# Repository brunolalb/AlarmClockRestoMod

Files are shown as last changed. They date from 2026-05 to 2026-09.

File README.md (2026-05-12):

# AlarmClockRestoMod
ESP32 Software for an Alarm Clock Resto Mod.

The idea is to use the components of an old alarm clock and replace the electronics with an ESP32, adding a lot of features to it. From an outside perspective, the clock will look as original as possible.

## Features

* WiFi connectivity
  * NTP time synchronization
  * Web server for advanced configuration
  * OTA updates
* Bluetooth connection from phone and to headphone/speaker
* Clock:
  * 7 segment display with dimming function
  * RTC for time keeping when power is out
* Alarms:
  * Configurable via web interface (advanced) or via buttons (only next alarm)
  * Configurable music or internet radio or buzzer for each alarm
  * Snooze function (delay configurable via web interface)
  * Vacation mode (turn off all alarms for a configurable period of time)
* Radio:
  * Internet radio stations configurable via web interface
  * Tuner button to switch between internet radio stations or playlists on microSD card
* microSD Card to store pre-owned Music, playlists and configuration files

## Components Overview
* Display is a 7 segment 4 digits with a TM1637, dimmable by software
* DS3231 for time keeping when power is out
* microSD Card with:
  * MP3 songs and playlists
  * Configuration file for radio stations (accepts internet radio station or playlist)
  * Configuration file for different alarms
* The tuner button of the alarm clock is a variable capacitor (10 - 500pF) read via a MPR121
  * Each frequency corresponds to an internet radio
* Bluetooth to connect to cellphone (play music from it) or to an external speaker/headphone
* Normal speaker connected via MAX98357A
* Buttons (Telefunken Digital Electronic 101):
  * 2 momentary switches to set time (Fast and slow)
  * 1 latching switch to turn on auto dimm/full light on display
  * 3 mutually-exclusive latching switches: show time, show next alarm (use the 2 momentary switches to set the alarm time) or "sleep mode" (turn on radio for 60min)
  * 1 momentary switch for sleep function (during alarm, press once to delay alarm in 5min, press twice to turn off alarm; during sleep mode, turn off radio)
  * 1 Volume slider (potentiometer)
  * 4 mutually-exclusive latching switches: turn on radio, turn off radio, alarm with radio, alarm with buzzing sound
  * 2 mutually-exclusive latching switches: radio corresponds to playlists, radio corresponds to internet radios
  * 1 momentary switch: one click (tries to connect to configured bluetooth speaker), two clicks (turns on bluetooth for phone to connect); if bluetooth connection is not successful after 1 min, turn off bluetooth
* Alarms:
  * fully configurable via web interface
  * choose days of the week
  * snooze time configurable
  * vacation mode
  * music and internet radio configured via web interface

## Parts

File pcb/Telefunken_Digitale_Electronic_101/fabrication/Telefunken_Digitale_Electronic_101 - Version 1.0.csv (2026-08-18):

DNP | Reference | Qty | Name | Value | Description | Footprint
 | C1,C3,C7 | 3 |  | 100n | Unpolarized capacitor | Capacitor_SMD:C_0603_1608Metric_Pad1.08x0.95mm_HandSolder
 | C2 | 1 |  | 10u | Polarized capacitor | Capacitor_THT:CP_Radial_D4.0mm_P2.00mm
 | C4,C8 | 2 |  | 10u | Unpolarized capacitor | Capacitor_SMD:C_0805_2012Metric_Pad1.18x1.45mm_HandSolder
 | C5,C6 | 2 |  | 100p | Unpolarized capacitor | Capacitor_SMD:C_0603_1608Metric_Pad1.08x0.95mm_HandSolder
 | DISPLAY1 | 1 | DISPLAY |  | 4 Digit 7-Segment Display with dots 0.8" | RadioWecker:8041BS-1
 | J1 | 1 | POWER | Conn_01x02_MountingPin | Generic connectable mounting pin connector, single row, 01x02, script generated (kicad-library-utils/schlib/autogen/connector/) | RadioWecker:JST_S2B-XH-SM4-TB
 | J2 | 1 | Display | Conn_01x02_MountingPin | Generic connectable mounting pin connector, single row, 01x02, script generated (kicad-library-utils/schlib/autogen/connector/) | Connector_Molex:Molex_PicoBlade_53261-0271_1x02-1MP_P1.25mm_Horizontal
 | J3 | 1 | RTC | Conn_01x04_MountingPin | Generic connectable mounting pin connector, single row, 01x04, script generated (kicad-library-utils/schlib/autogen/connector/) | Connector_Molex:Molex_PicoBlade_53261-0471_1x04-1MP_P1.25mm_Horizontal
 | J4 | 1 | BT_TIME | Conn_01x02_Socket | Generic connector, single row, 01x02, script generated | Connector_PinSocket_2.54mm:PinSocket_1x02_P2.54mm_Vertical
 | J5 | 1 | BT_SIGNAL | Conn_01x02_Socket | Generic connector, single row, 01x02, script generated | Connector_PinSocket_2.54mm:PinSocket_1x02_P2.54mm_Vertical
 | J6 | 1 | BT_SLEEP_FRONT | Conn_01x02_Socket | Generic connector, single row, 01x02, script generated | Connector_PinSocket_2.54mm:PinSocket_1x02_P2.54mm_Vertical
 | J7 | 1 | BT_ILLUM | Conn_01x02_Socket | Generic connector, single row, 01x02, script generated | Connector_PinSocket_2.54mm:PinSocket_1x02_P2.54mm_Vertical
 | J8 | 1 | BT_SLEEP_TOP | Conn_01x02_Socket | Generic connector, single row, 01x02, script generated | Connector_PinSocket_2.54mm:PinSocket_1x02_P2.54mm_Vertical
 | R3,R4 | 2 |  | 10K | Resistor | Resistor_SMD:R_0603_1608Metric_Pad0.98x0.95mm_HandSolder
 | SW1 | 1 | FAST | SW_Push | Push button switch, generic, two pins | RadioWecker:TACT_SWITCH_3.2X4.2X2.5MM
 | SW2 | 1 | SLOW | SW_Push | Push button switch, generic, two pins | RadioWecker:TACT_SWITCH_3.2X4.2X2.5MM
 | U1 | 1 |  | DS3231 | DS3231 AT24C32 IIC module precision Real time clock quare memory for Arduino | RadioWecker:DS3231
 | U2 | 1 |  | TM1637_SOP20 | LED Drive Control Special Circuit | RadioWecker:SOIC127P1035X255-20N
DNP | R1,R2 | 2 |  | 2k2 | Resistor | Resistor_SMD:R_0603_1608Metric_Pad0.98x0.95mm_HandSolder

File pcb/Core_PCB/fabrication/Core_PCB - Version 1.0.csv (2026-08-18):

DNP | Reference | Name | Qty | Value | Description | Footprint
 | A1 |  | 1 | Arduino_Nano_ESP32_Socket | Socket for Arduino Nano ESP32 | RadioWecker:Arduino_Nano_ESP32_Socket
 | C1 |  | 1 | 10u | Polarized capacitor | Capacitor_THT:CP_Radial_D4.0mm_P2.00mm
 | C2,C3,C5,C8,C9,C10,C11,C12,C14,C15,C16,C17 |  | 12 | 100n | Unpolarized capacitor | Capacitor_SMD:C_0603_1608Metric_Pad1.08x0.95mm_HandSolder
 | C4,C6,C7 |  | 3 | 10u | Unpolarized capacitor | Capacitor_SMD:C_0805_2012Metric_Pad1.18x1.45mm_HandSolder
 | C13 |  | 1 | 1u | Unpolarized capacitor | Capacitor_SMD:C_0805_2012Metric_Pad1.18x1.45mm_HandSolder
 | J1 | POWER | 1 | Conn_01x02_MountingPin | Generic connectable mounting pin connector, single row, 01x02, script generated (kicad-library-utils/schlib/autogen/connector/) | RadioWecker:JST_S2B-XH-SM4-TB
 | J2 | DISPLAY_POWER | 1 | Conn_01x02_MountingPin | Generic connectable mounting pin connector, single row, 01x02, script generated (kicad-library-utils/schlib/autogen/connector/) | RadioWecker:JST_S2B-XH-SM4-TB
 | J3 | DISPLAY | 1 | Conn_01x02_MountingPin | Generic connectable mounting pin connector, single row, 01x02, script generated (kicad-library-utils/schlib/autogen/connector/) | Connector_Molex:Molex_PicoBlade_53261-0271_1x02-1MP_P1.25mm_Horizontal
 | J4 | RTC | 1 | Conn_01x04_MountingPin | Generic connectable mounting pin connector, single row, 01x04, script generated (kicad-library-utils/schlib/autogen/connector/) | Connector_Molex:Molex_PicoBlade_53261-0471_1x04-1MP_P1.25mm_Horizontal
 | J5 | SDCARD | 1 | Conn_01x06 | Generic connector, single row, 01x06, script generated (kicad-library-utils/schlib/autogen/connector/) | Connector_PinSocket_2.54mm:PinSocket_1x06_P2.54mm_Vertical
 | J7 | DISPLAY_LED | 1 | Conn_01x02_MountingPin | Generic connectable mounting pin connector, single row, 01x02, script generated (kicad-library-utils/schlib/autogen/connector/) | RadioWecker:JST_S2B-XH-SM4-TB
 | J8 |  | 1 | Conn_01x08 | Generic connector, single row, 01x08, script generated (kicad-library-utils/schlib/autogen/connector/) | Connector_PinSocket_2.54mm:PinSocket_1x08_P2.54mm_Vertical
 | J10 | TOUCH | 1 | Conn_02x12_Odd_Even | Generic connector, double row, 02x12, odd/even pin numbering scheme (row 1 odd numbers, row 2 even numbers), script generated (kicad-library-utils/schlib/autogen/connector/) | Connector_PinSocket_2.54mm:PinSocket_2x12_P2.54mm_Vertical
 | J11 | VOLUME | 1 | Conn_01x03_MountingPin | Generic connectable mounting pin connector, single row, 01x03, script generated (kicad-library-utils/schlib/autogen/connector/) | Connector_Molex:Molex_PicoBlade_53261-0371_1x03-1MP_P1.25mm_Horizontal
 | Q1 |  | 1 | BSN20 | 0.5A Id, 50V Vds, N-Channel MOSFET, SOT-23 | Package_TO_SOT_SMD:SOT-23
 | R1,R2 |  | 2 | 100k | Resistor | Resistor_SMD:R_0603_1608Metric_Pad0.98x0.95mm_HandSolder
 | R3,R4 |  | 2 | 1k | Resistor | Resistor_SMD:R_0603_1608Metric_Pad0.98x0.95mm_HandSolder
 | R5,R6,R7,R8,R9,R10,R11,R12 |  | 8 | 10k | Resistor | Resistor_SMD:R_0603_1608Metric_Pad0.98x0.95mm_HandSolder
 | R20,R21 |  | 2 | 2K2 | Resistor | Resistor_SMD:R_0603_1608Metric_Pad0.98x0.95mm_HandSolder
 | SW1 | BOOT0 | 1 | SW_Push | Push button switch, generic, two pins | Button_Switch_THT:SW_PUSH_6mm
 | SW2 | BOOT1 | 1 | SW_Push | Push button switch, generic, two pins | Button_Switch_THT:SW_PUSH_6mm
 | SW3 | RESET | 1 | SW_Push | Push button switch, generic, two pins | Button_Switch_THT:SW_PUSH_6mm
 | U1 |  | 1 | MAX98357A | Adafruit 3006, Mono I2S Amplifier, MAX98357A | RadioWecker:MAX98357A_Adafruit
 | U2 |  | 1 | HEF4051BT | 8-channel analog multiplexer / demultiplexer, 3.0..15.0V supply voltage, SOIC-16 | Package_SO:SOIC-16_3.9x9.9mm_P1.27mm
 | U3 |  | 1 | MPR121_BREAKOUT | Capacitive Touch Sensor Breakout - MPR121, Sparkfun SEN-09695, Adafruit 1982 | RadioWecker:MPR121_BREAKOUT
 | U4 |  | 1 | MCP23017x-x-SS | 16-bit I/O expander, I2C, interrupts, w pull-ups, SSOP-28 | Package_SO:SSOP-28_5.3x10.2mm_P0.65mm
DNP | C18,C19,C20,C21,C22,C23,C24 |  | 7 | 100n | Unpolarized capacitor | Capacitor_SMD:C_0603_1608Metric_Pad1.08x0.95mm_HandSolder
DNP | J6 | SPEAKER | 1 | Screw_Terminal_01x02 | Generic screw terminal, single row, 01x02, script generated (kicad-library-utils/schlib/autogen/connector/) | TerminalBlock_Phoenix:TerminalBlock_Phoenix_PT-1,5-2-3.5-H_1x02_P3.50mm_Horizontal
DNP | J9 |  | 1 | Conn_01x08 | Generic connector, single row, 01x08, script generated (kicad-library-utils/schlib/autogen/connector/) | Connector_PinSocket_2.54mm:PinSocket_1x08_P2.54mm_Vertical
DNP | R13,R14,R15,R16,R17,R18,R19 |  | 7 | 10k | Resistor | Resistor_SMD:R_0603_1608Metric_Pad0.98x0.95mm_HandSolder

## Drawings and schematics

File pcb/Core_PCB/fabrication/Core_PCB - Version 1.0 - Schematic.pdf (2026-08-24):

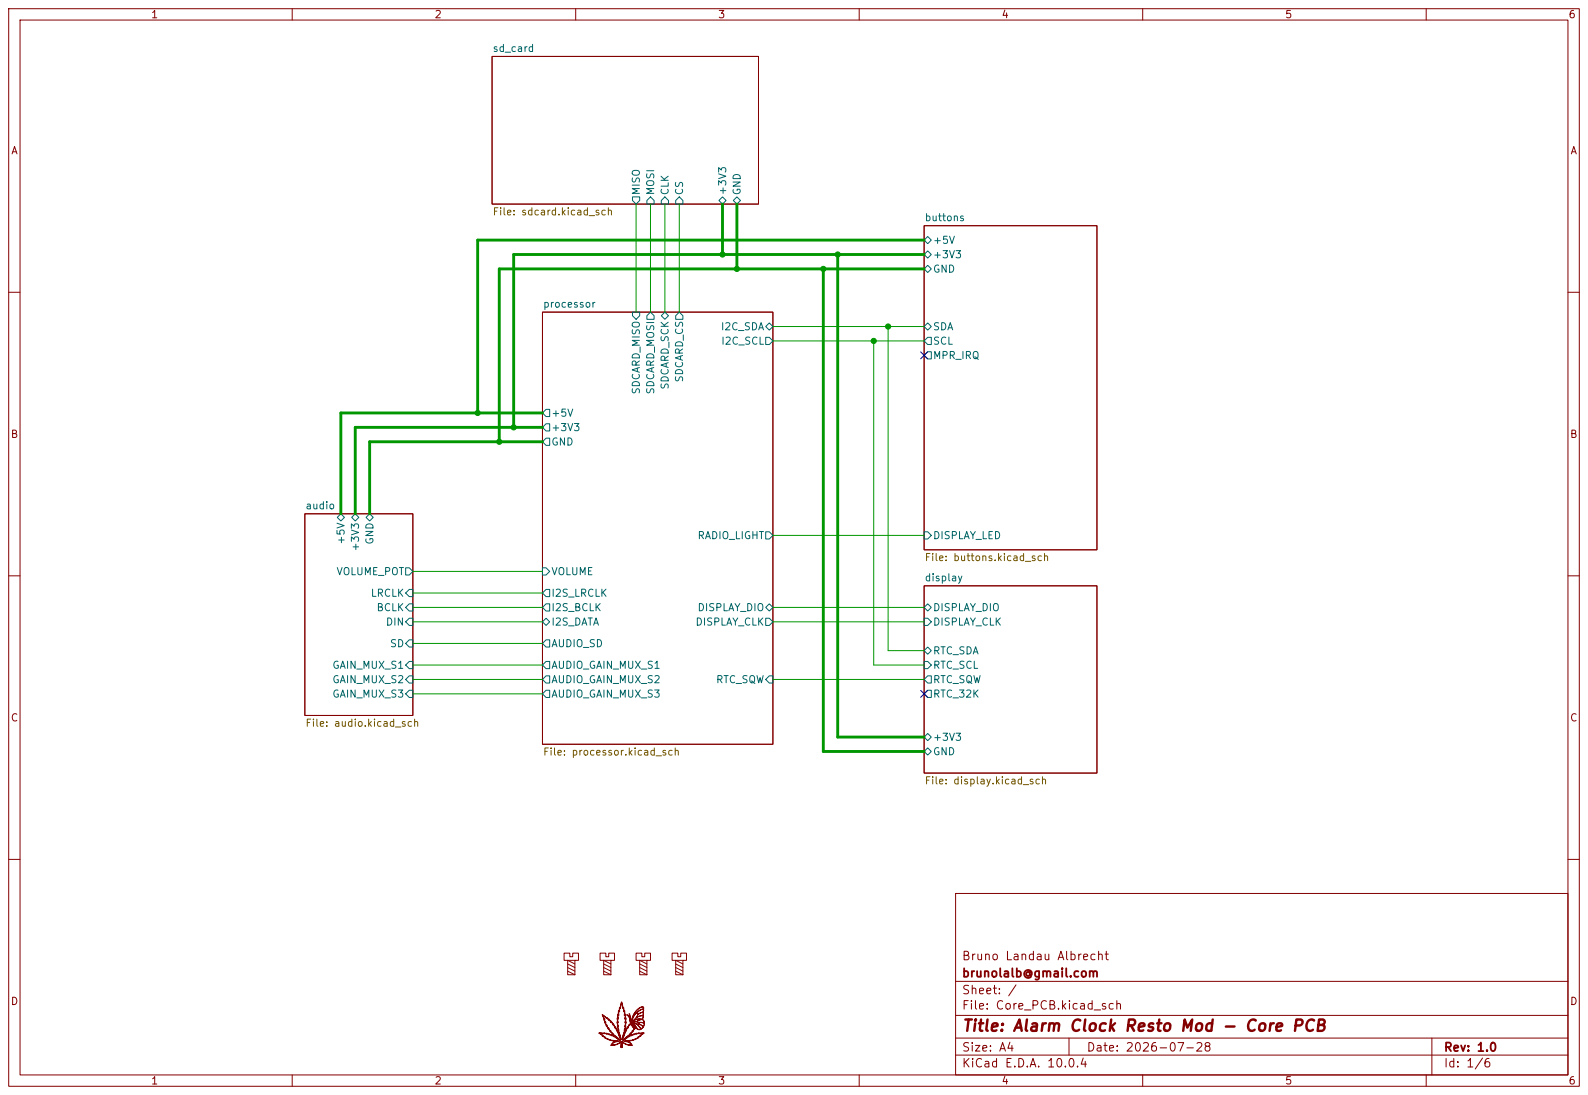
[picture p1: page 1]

SDA SCL +3V3 +5V buttons File: buttons.kicad_sch
GND MPR_IRQ

Bruno Landau Albrecht LRCLK
BCLK
DIN

brunolalb@gmail.com
Sheet: /
File: Core_PCB.kicad_sch
Title: Alarm Clock Resto Mod - Core PCB

Size: A4 | Rev: 1.0
KiCad E.D.A. 10.0.4 | Id: 1/6

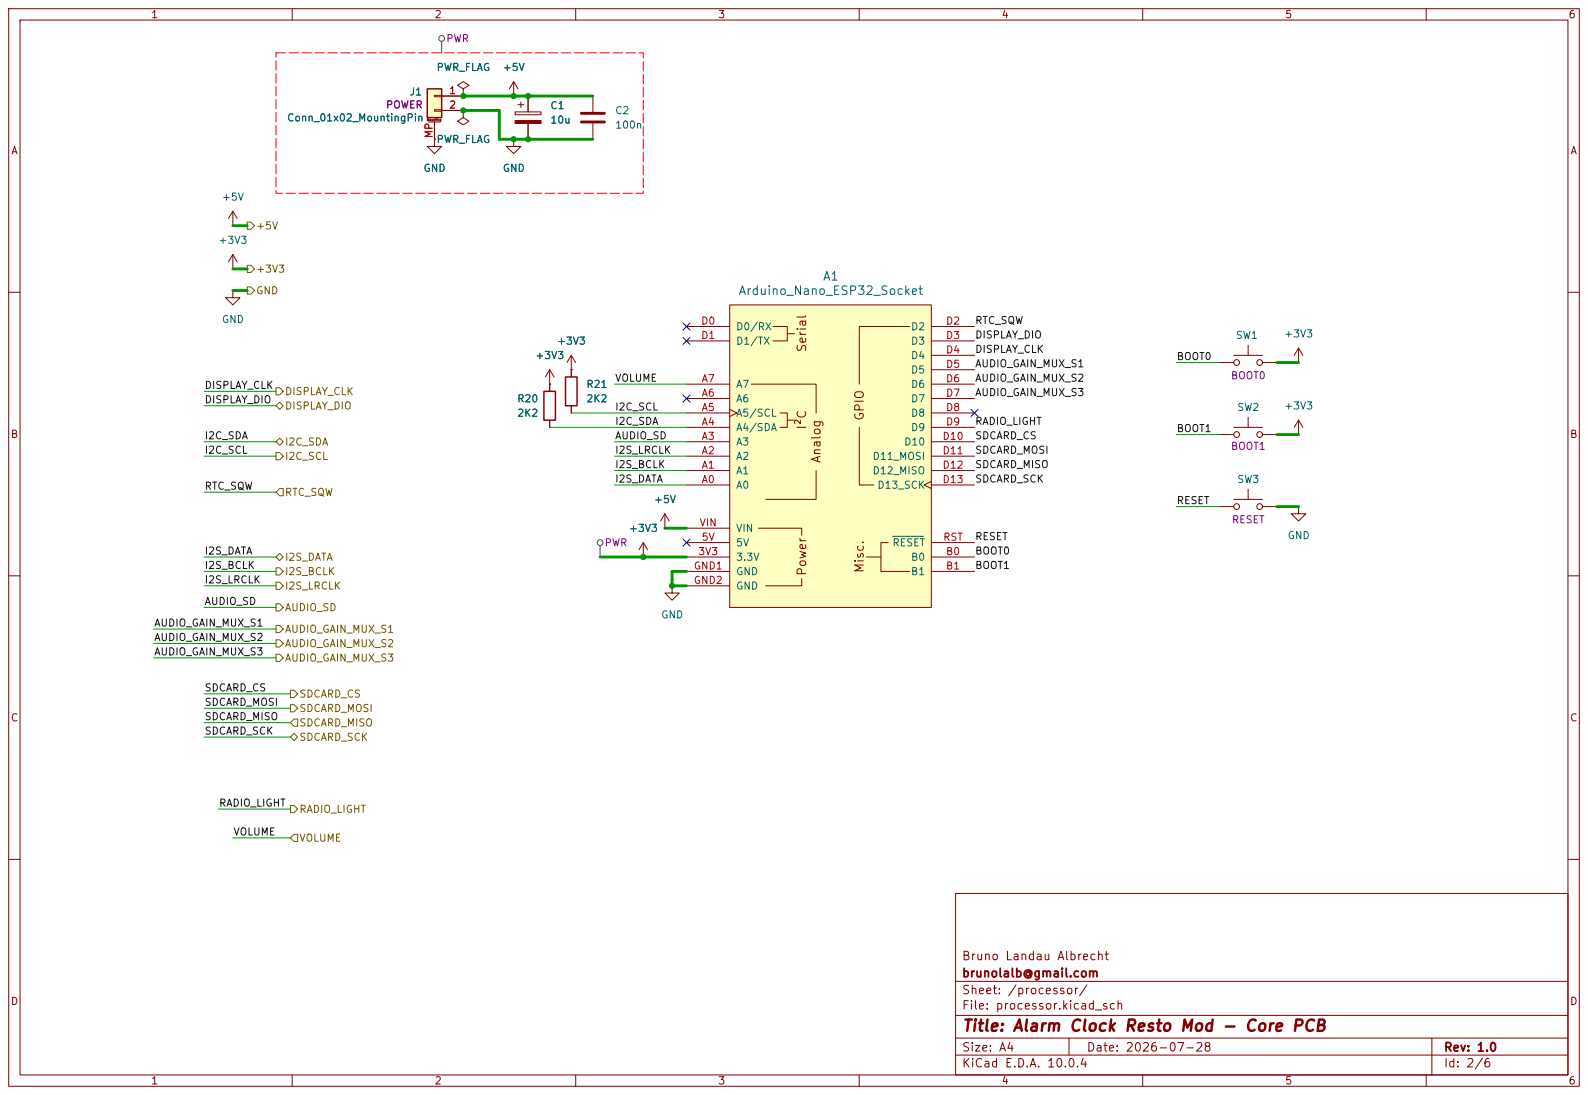
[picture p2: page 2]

Bruno Landau Albrecht
brunolalb@gmail.com
Sheet: /processor/
File: processor.kicad_sch
Title: Alarm Clock Resto Mod - Core PCB

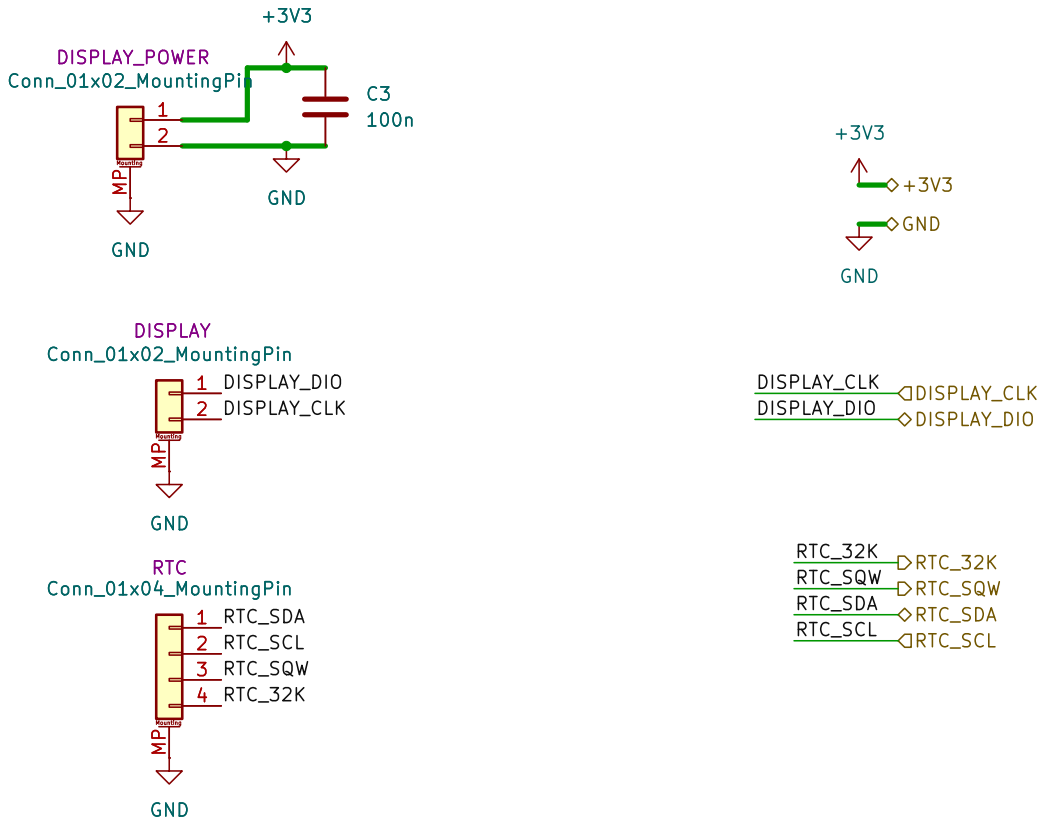
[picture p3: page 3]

Bruno Landau Albrecht
brunolalb@gmail.com
Sheet: /display/
File: display.kicad_sch
Title: Alarm Clock Resto Mod - Core PCB

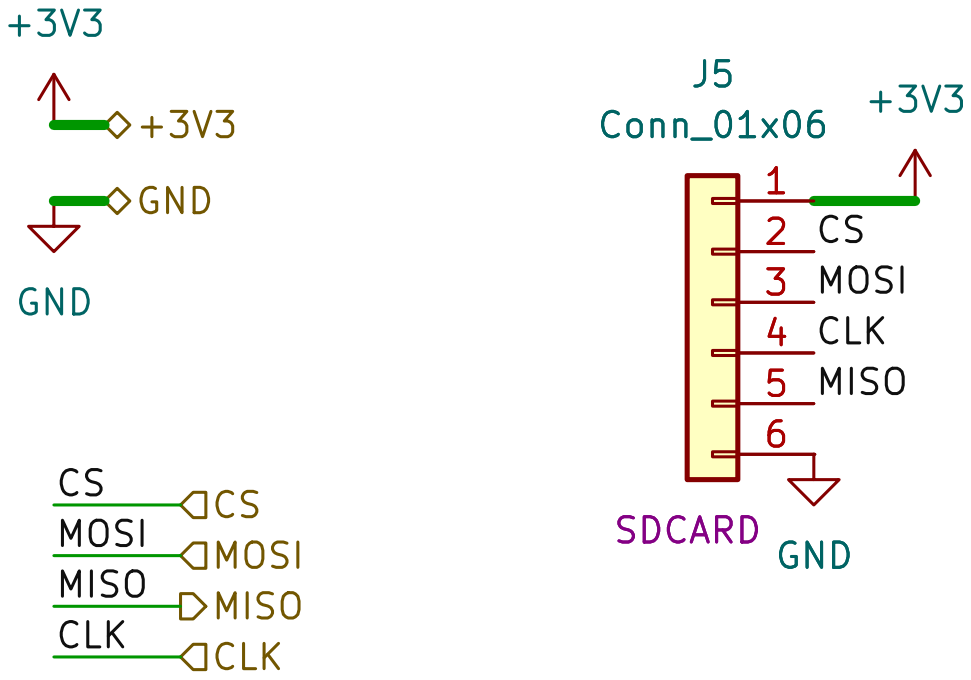
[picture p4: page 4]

GND +3V3
CLK MISO +3V3 GNDMOSI CS MISO

Bruno Landau Albrecht
brunolalb@gmail.com
Sheet: /sd_card/
File: sdcard.kicad_sch
Title: Alarm Clock Resto Mod - Core PCB

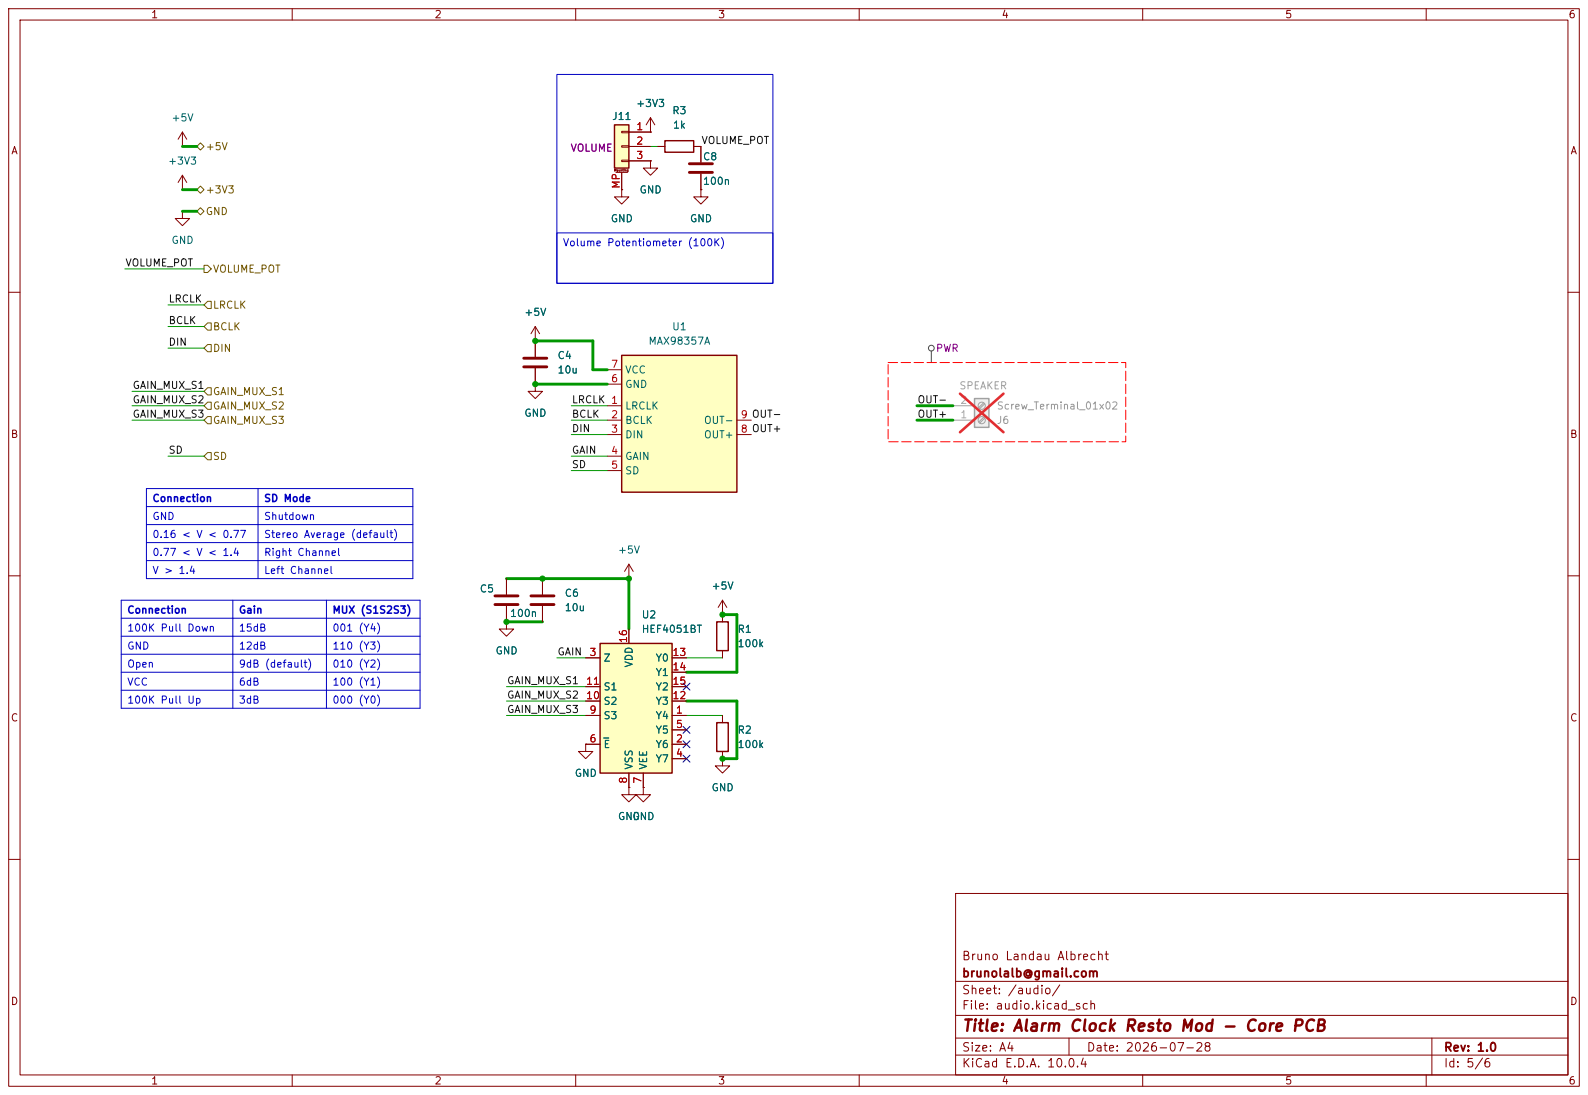
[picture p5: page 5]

Bruno Landau Albrecht GNDGND

brunolalb@gmail.com
Sheet: /audio/
File: audio.kicad_sch
Title: Alarm Clock Resto Mod - Core PCB

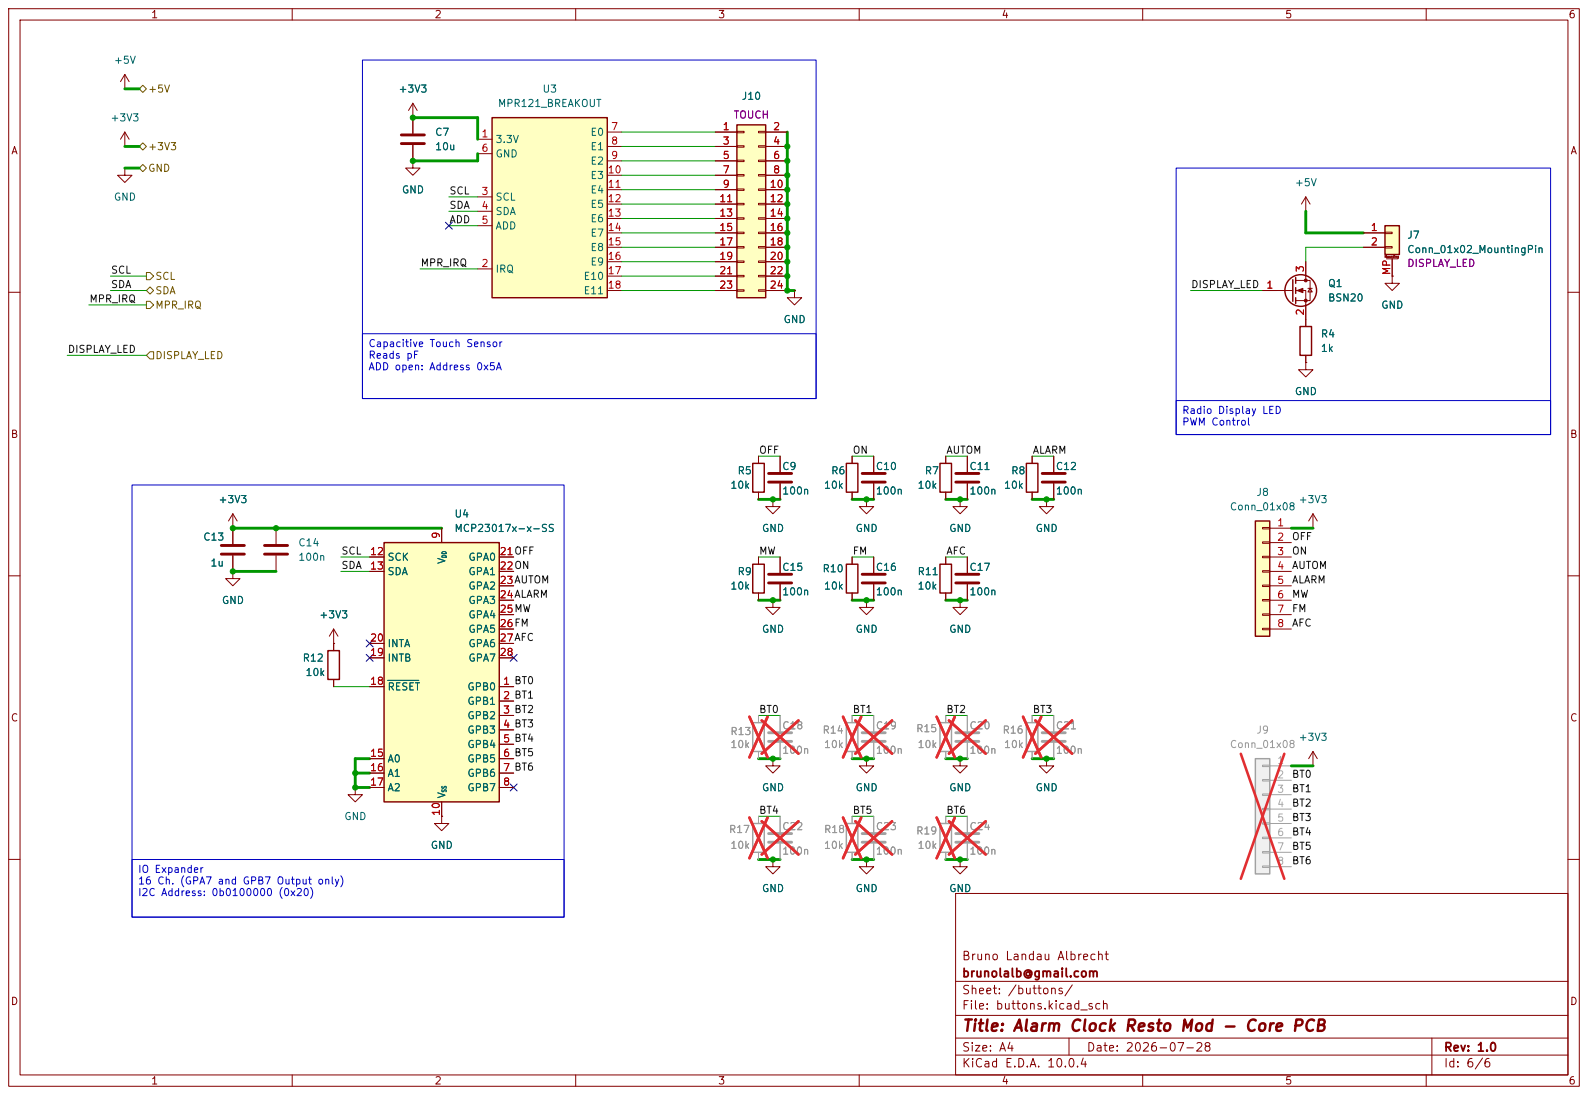
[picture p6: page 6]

Capacitive Touch Sensor Reads pF

IO Expander 16 Ch. (GPA7 and GPB7 Output only)

Bruno Landau Albrecht
brunolalb@gmail.com
Sheet: /buttons/
File: buttons.kicad_sch
Title: Alarm Clock Resto Mod - Core PCB

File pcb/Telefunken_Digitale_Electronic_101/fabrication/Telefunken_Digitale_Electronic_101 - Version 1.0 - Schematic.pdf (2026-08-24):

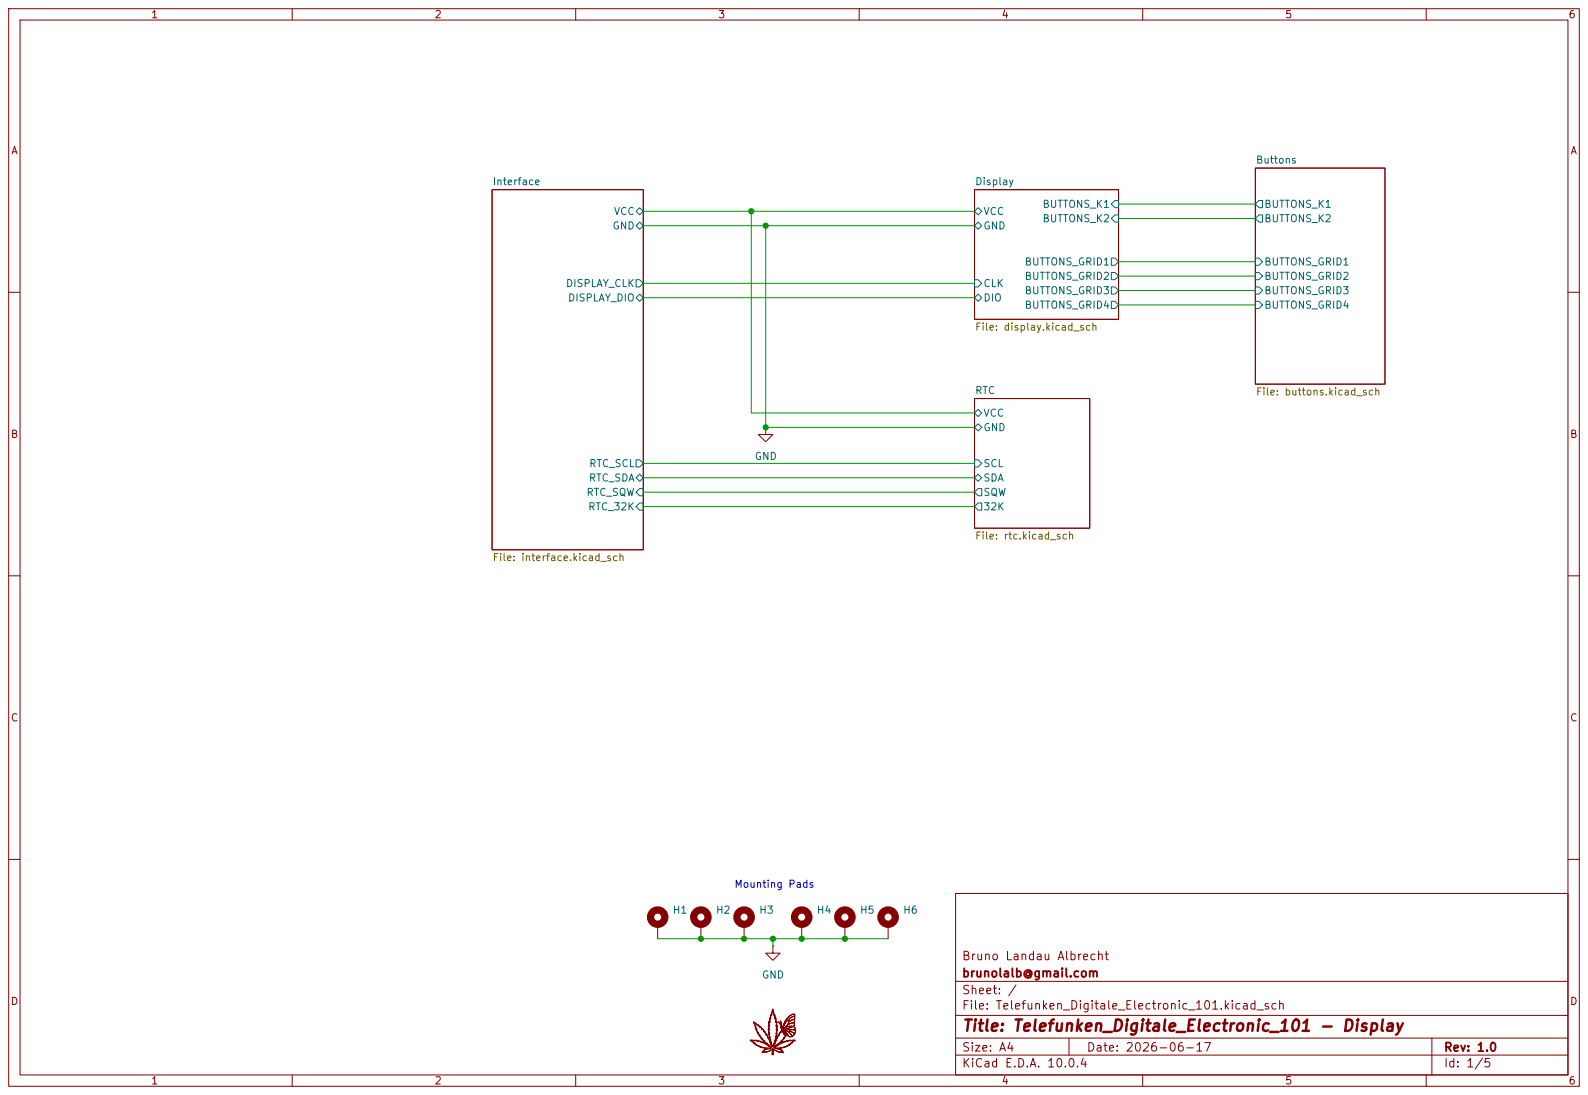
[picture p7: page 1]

Size: A4 | Rev: 1.0
KiCad E.D.A. 10.0.4 | Id: 1/5

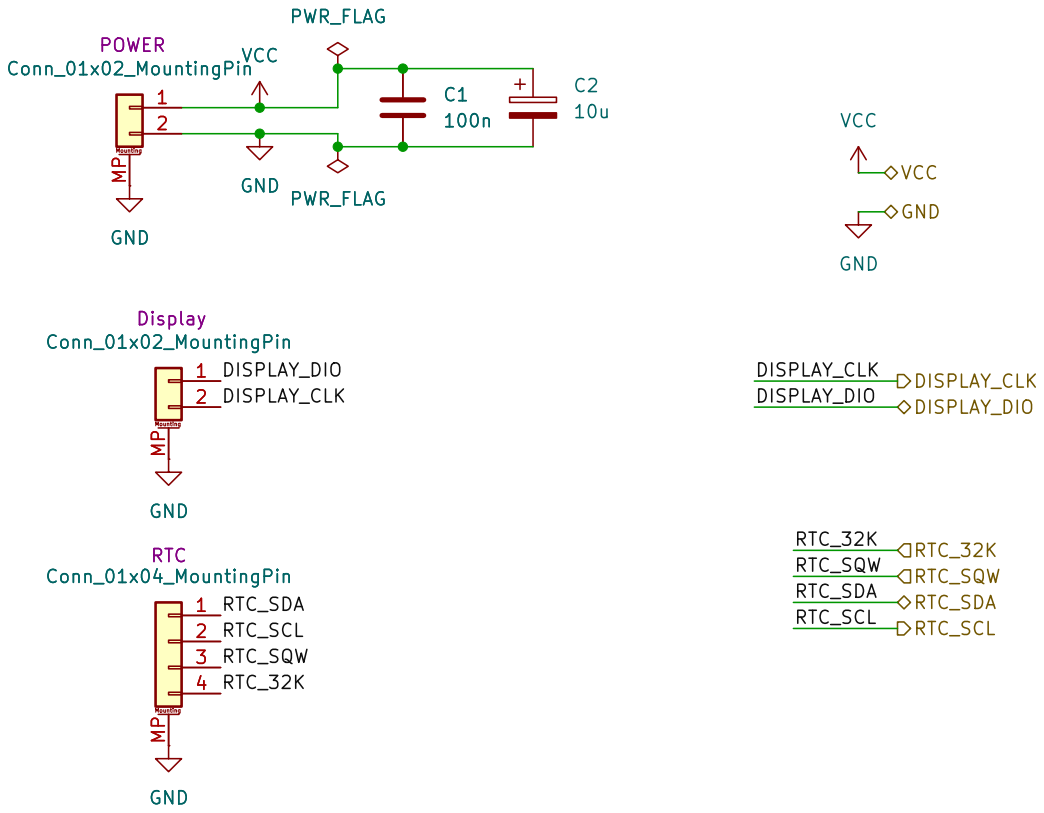
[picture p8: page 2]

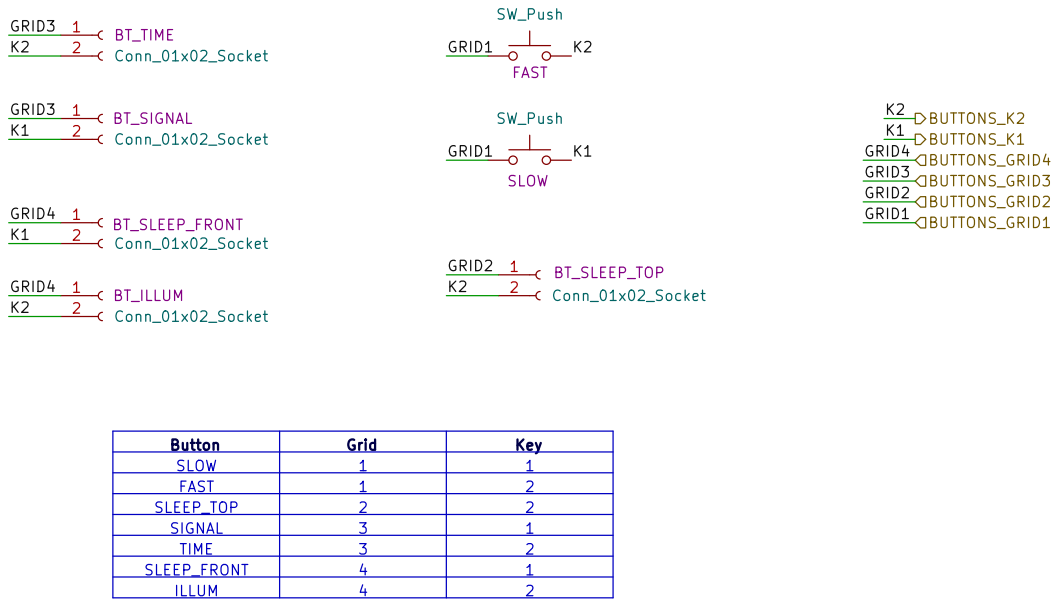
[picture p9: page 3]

FAST | 1 | 2
SLEEP_TOP | 2 | 2
SIGNAL | 3 | 1
TIME | 3 | 2
SLEEP_FRONT | 4 | 1
ILLUM | 4 | 2

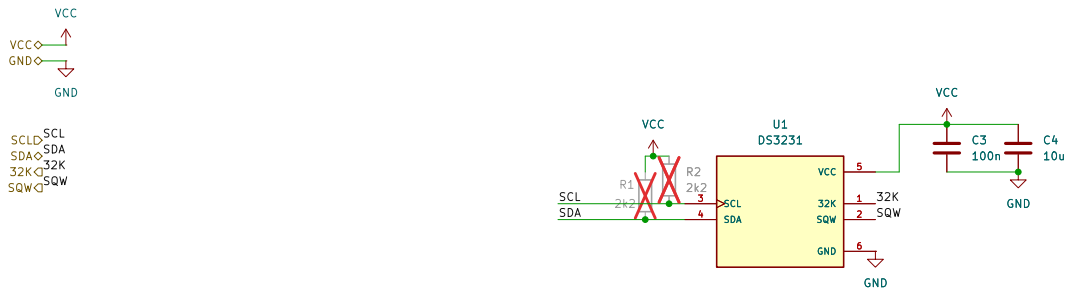
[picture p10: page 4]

SCL 32K
SDA SCL 32K
SDA SCL SDA SQW

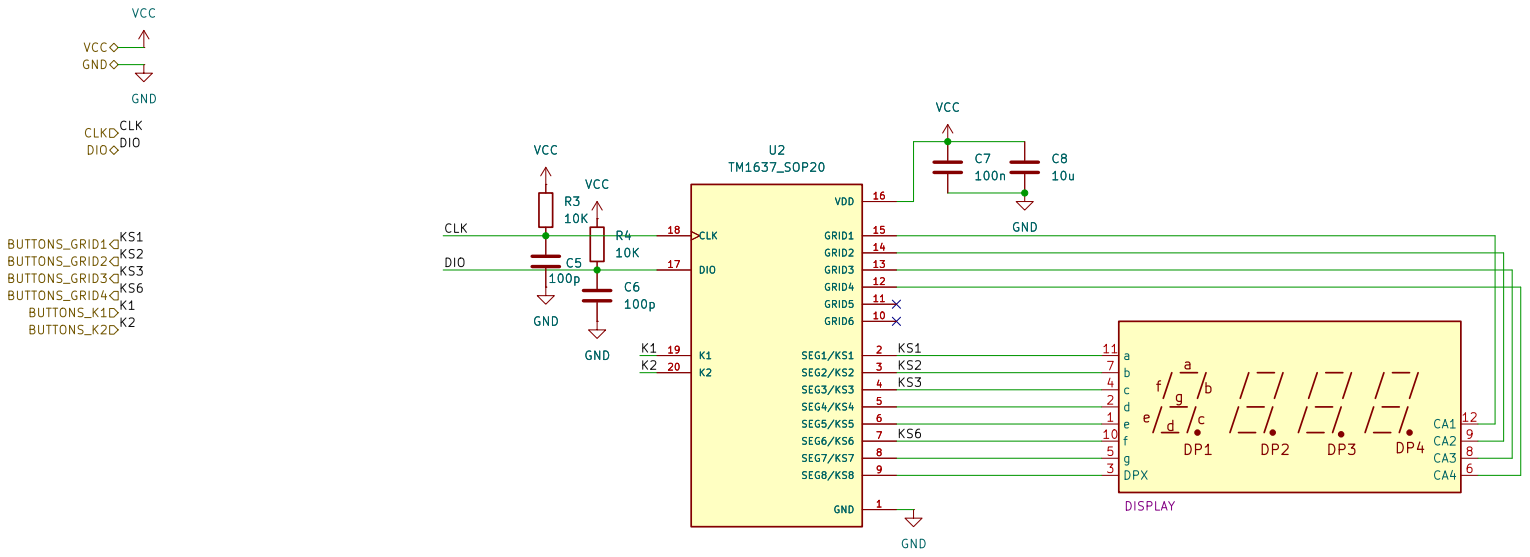
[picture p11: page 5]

Bruno Landau Albrecht GND

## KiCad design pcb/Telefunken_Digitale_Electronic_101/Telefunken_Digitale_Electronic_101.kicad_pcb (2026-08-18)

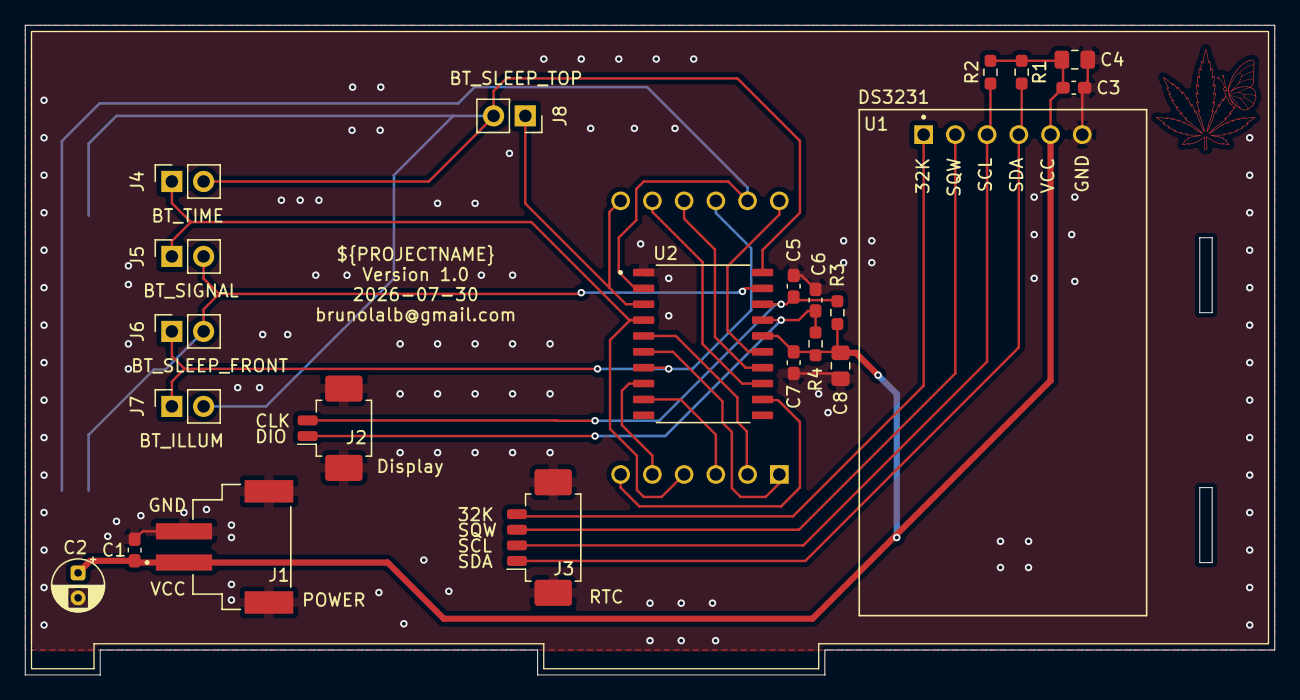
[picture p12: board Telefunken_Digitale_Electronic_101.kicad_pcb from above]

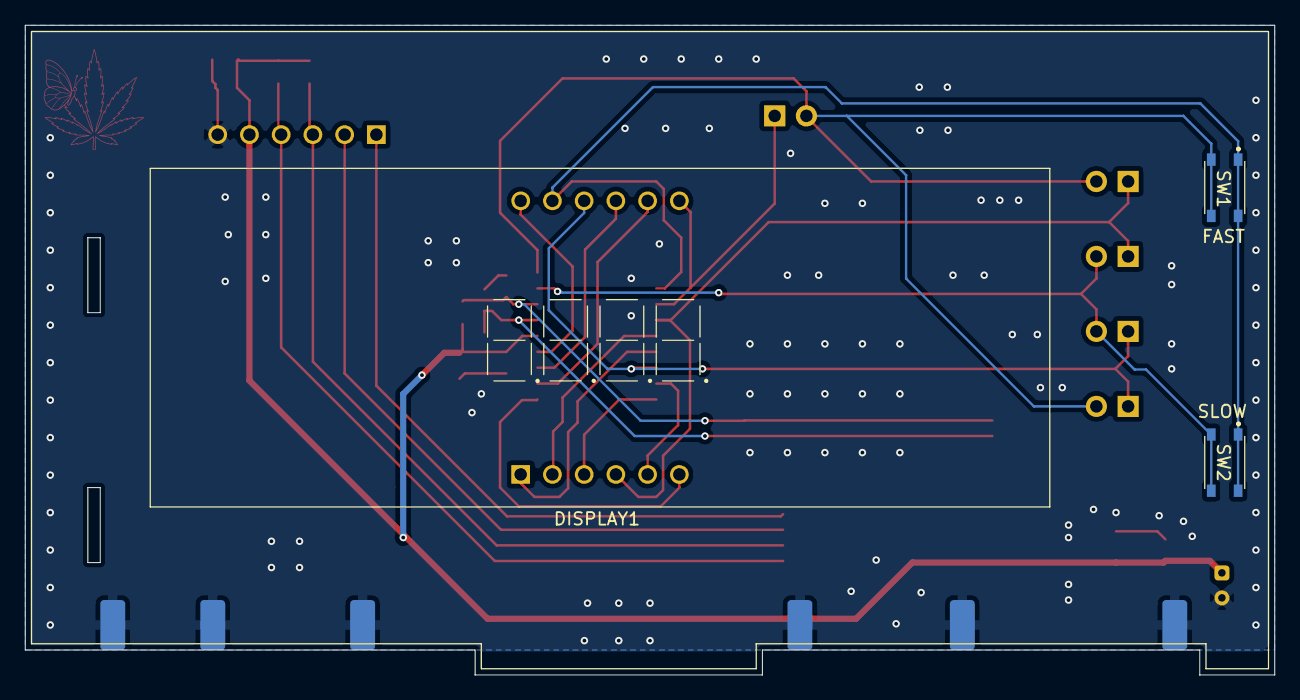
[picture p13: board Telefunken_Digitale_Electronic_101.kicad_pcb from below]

Board: 2 copper layers, 100.0 x 52.0 mm, 32 parts (9 on the bottom side), 22 nets.

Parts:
C1, C3, C7: 100n; C_0603_1608Metric_Pad1.08x0.95mm_HandSolder
C2: 10u; CP_Radial_D4.0mm_P2.00mm
C4, C8: 10u; C_0805_2012Metric_Pad1.18x1.45mm_HandSolder
C5, C6: 100p; C_0603_1608Metric_Pad1.08x0.95mm_HandSolder
DISPLAY1: 8041BS-1
G1: LOGO
H1, H2, H3, H4, H5, H6: MountingHole_Pad_MP; BOARD_TO_BOARD_PAD_SMD
J1: Conn_01x02_MountingPin; JST_S2B-XH-SM4-TB
J2: Conn_01x02_MountingPin; Molex_PicoBlade_53261-0271_1x02-1MP_P1.25mm_Horizontal
J3: Conn_01x04_MountingPin; Molex_PicoBlade_53261-0471_1x04-1MP_P1.25mm_Horizontal
J4, J5, J6, J7, J8: Conn_01x02_Socket; PinSocket_1x02_P2.54mm_Vertical
R1, R2: 2k2; R_0603_1608Metric_Pad0.98x0.95mm_HandSolder
R3, R4: 10K; R_0603_1608Metric_Pad0.98x0.95mm_HandSolder
SW1, SW2: SW_Push; TACT_SWITCH_3.2X4.2X2.5MM
U1: DS3231
U2: TM1637_SOP20; SOIC127P1035X255-20N

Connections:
/Buttons/GRID1: DISPLAY1.11 (a), SW1.1, SW2.1, U2.2 (SEG1/KS1)
/Buttons/GRID2: DISPLAY1.7 (b), J8.1, U2.3 (SEG2/KS2)
/Buttons/GRID3: DISPLAY1.4 (c), J4.1, J5.1, U2.4 (SEG3/KS3)
/Buttons/GRID4: DISPLAY1.10 (f), J6.1, J7.1, U2.7 (SEG6/KS6)
/Buttons/K1: J5.2, J6.2, SW2.2, U2.19 (K1)
/Buttons/K2: J4.2, J7.2, J8.2, SW1.2, U2.20 (K2)
/Display/CLK: C5.1, J2.2, R3.2, U2.18 (CLK)
/Display/DIO: C6.1, J2.1, R4.2, U2.17 (DIO)
/Interface/RTC_32K: J3.4, U1.1 (32K)
/Interface/RTC_SCL: J3.2, R2.2, U1.3 (SCL)
/Interface/RTC_SDA: J3.1, R1.2, U1.4 (SDA)
/Interface/RTC_SQW: J3.3, U1.2 (SQW)
GND: C1.2, C2.2, C3.2, C4.2, C5.2, C6.2, C7.2, C8.2, H1.MP (MP_MP), H2.MP (MP_MP), H3.MP (MP_MP), H4.MP (MP_MP), H5.MP (MP_MP), H6.MP (MP_MP), J1.2, J1.MP (MountPin), J2.MP (MountPin), J3.MP (MountPin), U1.6 (GND), U2.1 (GND)
unnamed: DISPLAY1.12 (CA1), U2.15 (GRID1)
unnamed: DISPLAY1.9 (CA2), U2.14 (GRID2)
unnamed: DISPLAY1.8 (CA3), U2.13 (GRID3)
unnamed: DISPLAY1.6 (CA4), U2.12 (GRID4)
unnamed: DISPLAY1.3 (DPX), U2.9 (SEG8/KS8)
unnamed: DISPLAY1.2 (d), U2.5 (SEG4/KS4)
unnamed: DISPLAY1.1 (e), U2.6 (SEG5/KS5)
unnamed: DISPLAY1.5 (g), U2.8 (SEG7/KS7)
VCC: C1.1, C2.1, C3.1, C4.1, C7.1, C8.1, J1.1, R1.1, R2.1, R3.1, R4.1, U1.5 (VCC), U2.16 (VDD)

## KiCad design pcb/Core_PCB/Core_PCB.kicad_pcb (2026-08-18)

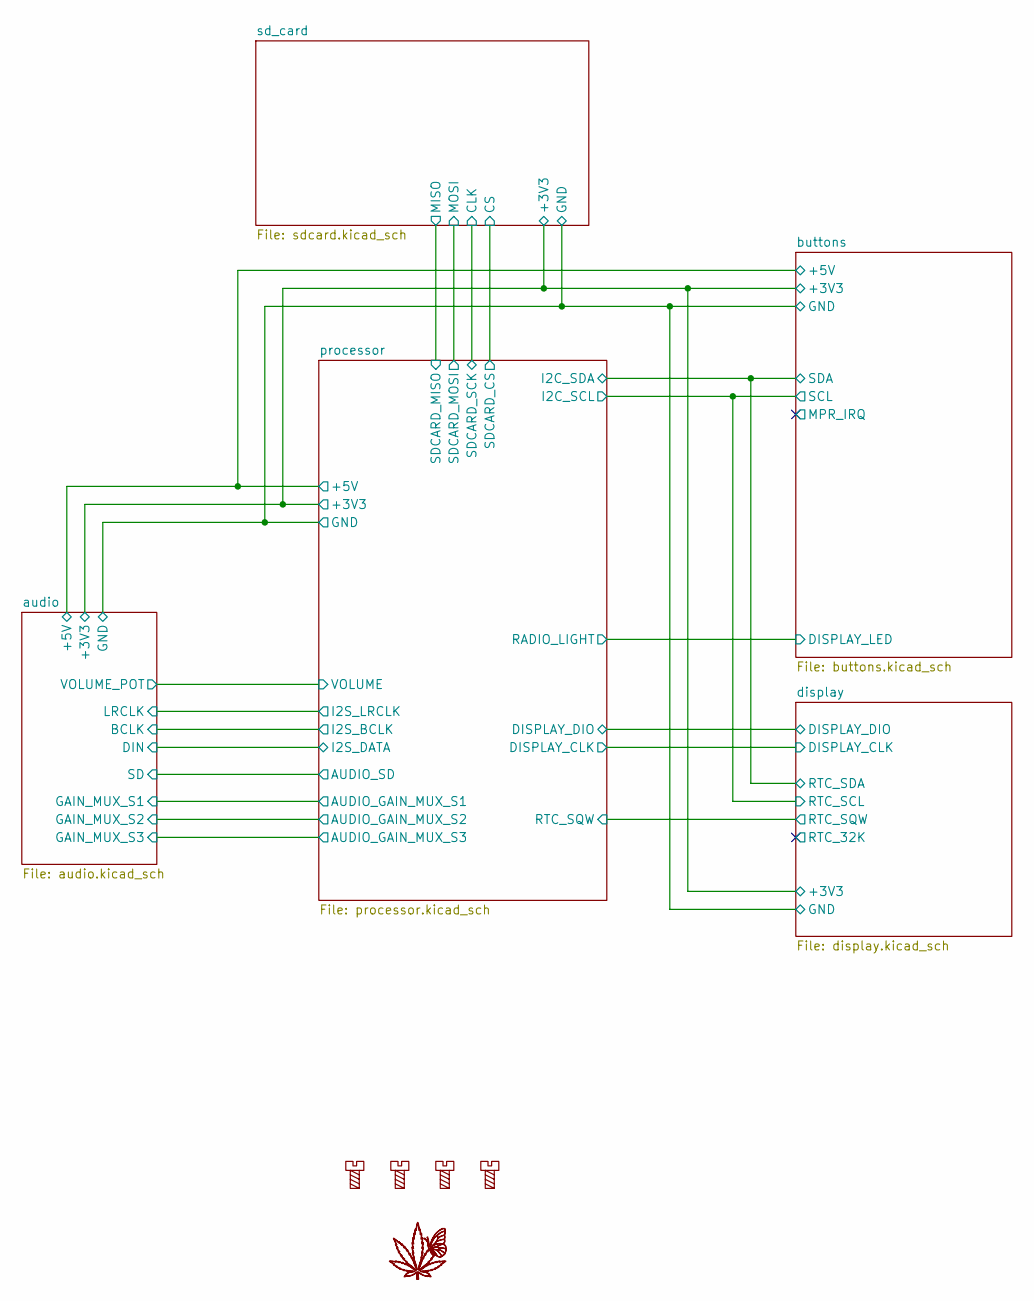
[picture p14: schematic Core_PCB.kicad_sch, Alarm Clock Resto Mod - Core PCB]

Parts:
G1: LOGO
H1, H2, H3, H4: MountingScrew; MountingHole_3.2mm_M3

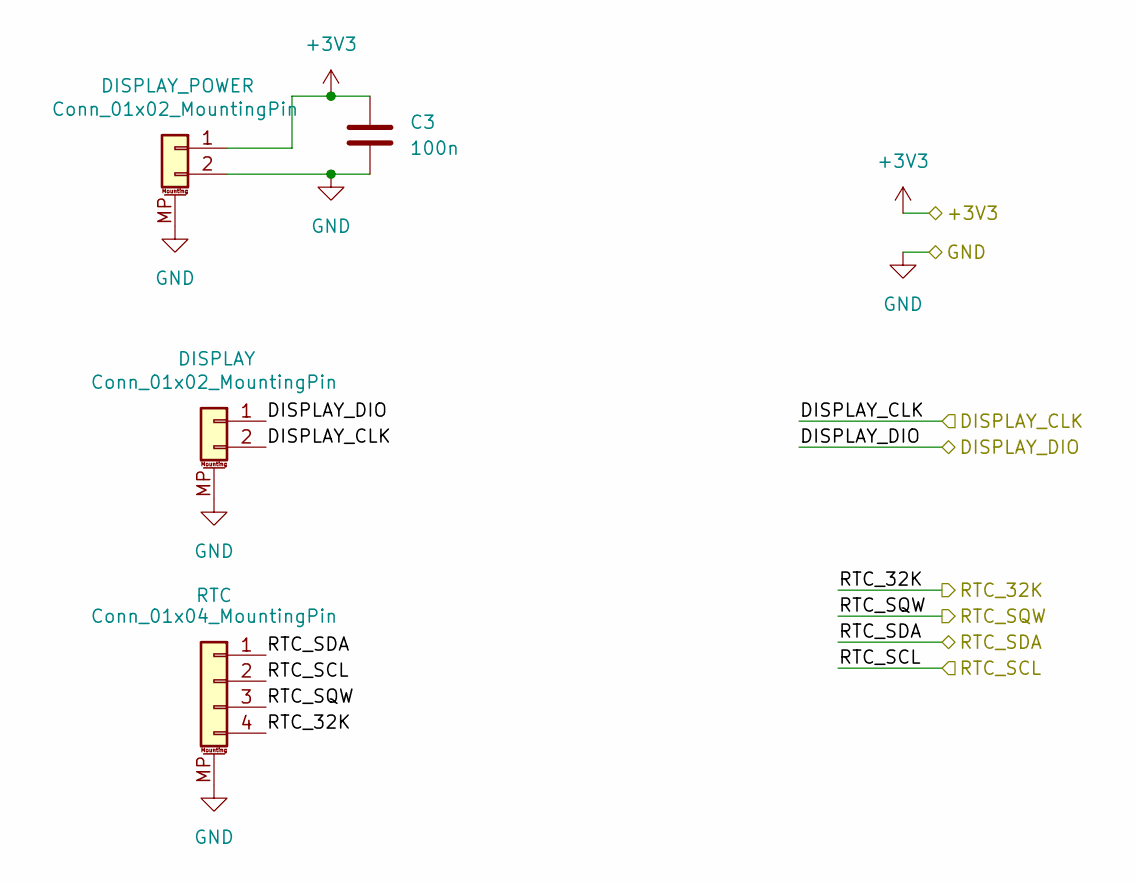
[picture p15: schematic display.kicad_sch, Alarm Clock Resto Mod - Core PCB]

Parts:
C3: 100n; C_0603_1608Metric_Pad1.08x0.95mm_HandSolder
J2: Conn_01x02_MountingPin; JST_S2B-XH-SM4-TB
J3: Conn_01x02_MountingPin; Molex_PicoBlade_53261-0271_1x02-1MP_P1.25mm_Horizontal
J4: Conn_01x04_MountingPin; Molex_PicoBlade_53261-0471_1x04-1MP_P1.25mm_Horizontal

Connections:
+3V3: C3.1, J2.1; also elsewhere on the board
/buttons/SCL: J4.2; also elsewhere on the board
/buttons/SDA: J4.1; also elsewhere on the board
/display/DISPLAY_CLK: J3.2; also elsewhere on the board
/display/DISPLAY_DIO: J3.1; also elsewhere on the board
/display/RTC_32K: J4.4
/display/RTC_SQW: J4.3; also elsewhere on the board
GND: C3.2, J2.2, J2.MP (MountPin), J3.MP (MountPin), J4.MP (MountPin); also elsewhere on the board

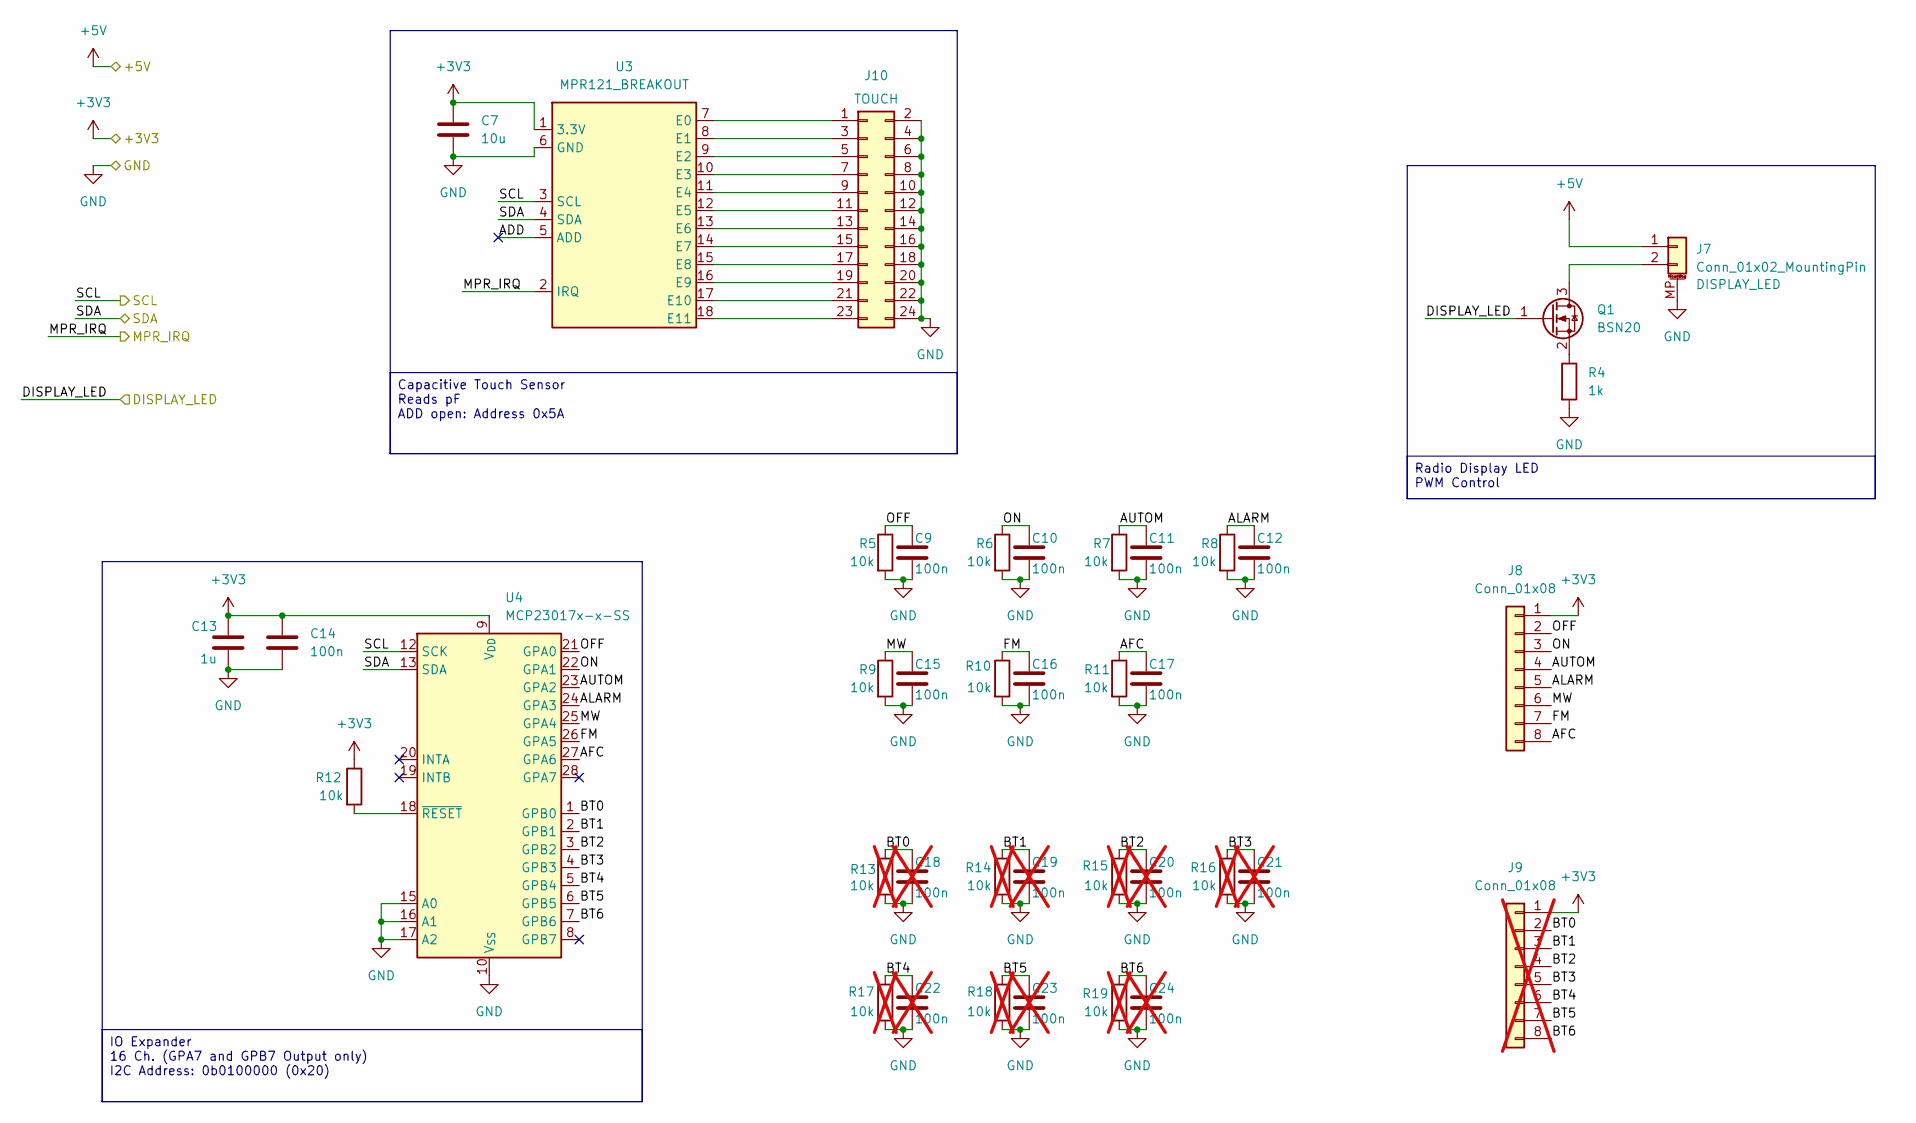
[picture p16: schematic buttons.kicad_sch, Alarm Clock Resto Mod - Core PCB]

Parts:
C7: 10u; C_0805_2012Metric_Pad1.18x1.45mm_HandSolder
C9, C10, C11, C12, C14, C15, C16, C17: 100n; C_0603_1608Metric_Pad1.08x0.95mm_HandSolder
C13: 1u; C_0805_2012Metric_Pad1.18x1.45mm_HandSolder
C18, C19, C20, C21, C22, C23, C24: 100n; C_0603_1608Metric_Pad1.08x0.95mm_HandSolder; not fitted
J7: Conn_01x02_MountingPin; JST_S2B-XH-SM4-TB
J8: Conn_01x08; PinSocket_1x08_P2.54mm_Vertical
J9: Conn_01x08; PinSocket_1x08_P2.54mm_Vertical; not fitted
J10: Conn_02x12_Odd_Even; PinSocket_2x12_P2.54mm_Vertical
Q1: BSN20; SOT-23
R4: 1k; R_0603_1608Metric_Pad0.98x0.95mm_HandSolder
R5, R6, R7, R8, R9, R10, R11, R12: 10k; R_0603_1608Metric_Pad0.98x0.95mm_HandSolder
R13, R14, R15, R16, R17, R18, R19: 10k; R_0603_1608Metric_Pad0.98x0.95mm_HandSolder; not fitted
U3: MPR121_BREAKOUT
U4: MCP23017x-x-SS; SSOP-28_5.3x10.2mm_P0.65mm

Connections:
+3V3: C7.1, C13.1, C14.1, J8.1, J9.1, R12.1, U3.1 (3.3V), U4.9 (V_{DD}); also elsewhere on the board
+5V: J7.1; also elsewhere on the board
/buttons/ADD: U3.5 (ADD)
/buttons/AFC: C17.1, J8.8, R11.1, U4.27 (GPA6)
/buttons/ALARM: C12.1, J8.5, R8.1, U4.24 (GPA3)
/buttons/AUTOM: C11.1, J8.4, R7.1, U4.23 (GPA2)
/buttons/BT0: C18.1, J9.2, R13.1, U4.1 (GPB0)
/buttons/BT1: C19.1, J9.3, R14.1, U4.2 (GPB1)
/buttons/BT2: C20.1, J9.4, R15.1, U4.3 (GPB2)
/buttons/BT3: C21.1, J9.5, R16.1, U4.4 (GPB3)
/buttons/BT4: C22.1, J9.6, R17.1, U4.5 (GPB4)
/buttons/BT5: C23.1, J9.7, R18.1, U4.6 (GPB5)
/buttons/BT6: C24.1, J9.8, R19.1, U4.7 (GPB6)
/buttons/DISPLAY_LED: Q1.1 (G); also elsewhere on the board
/buttons/FM: C16.1, J8.7, R10.1, U4.26 (GPA5)
/buttons/MPR_IRQ: U3.2 (IRQ)
/buttons/MW: C15.1, J8.6, R9.1, U4.25 (GPA4)
/buttons/OFF: C9.1, J8.2, R5.1, U4.21 (GPA0)
/buttons/ON: C10.1, J8.3, R6.1, U4.22 (GPA1)
/buttons/SCL: U3.3 (SCL), U4.12 (SCK); also elsewhere on the board
/buttons/SDA: U3.4 (SDA), U4.13 (SDA); also elsewhere on the board
GND: C7.2, C9.2, C10.2, C11.2, C12.2, C13.2, C14.2, C15.2, C16.2, C17.2, C18.2, C19.2, C20.2, C21.2, C22.2, C23.2, C24.2, J7.MP (MountPin), J10.2, J10.4, J10.6, J10.8, J10.10, J10.12, J10.14, J10.16, J10.18, J10.20, J10.22, J10.24, R4.2, R5.2, R6.2, R7.2, R8.2, R9.2, R10.2, R11.2, R13.2, R14.2, R15.2, R16.2, R17.2, R18.2, R19.2, U3.6 (GND), U4.10 (V_{SS}), U4.15 (A0), U4.16 (A1), U4.17 (A2); also elsewhere on the board
unnamed: J7.2, Q1.3 (D)
unnamed: J10.1, U3.7 (E0)
unnamed: J10.3, U3.8 (E1)
unnamed: J10.5, U3.9 (E2)
unnamed: J10.7, U3.10 (E3)
unnamed: J10.9, U3.11 (E4)
unnamed: J10.11, U3.12 (E5)
unnamed: J10.13, U3.13 (E6)
unnamed: J10.15, U3.14 (E7)
unnamed: J10.17, U3.15 (E8)
unnamed: J10.19, U3.16 (E9)
unnamed: J10.21, U3.17 (E10)
unnamed: J10.23, U3.18 (E11)
unnamed: Q1.2 (S), R4.1
unnamed: R12.2, U4.18 (~RESET)

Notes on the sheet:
Capacitive Touch Sensor Reads pF ADD open: Address 0x5A
IO Expander 16 Ch. (GPA7 and GPB7 Output only) I2C Address: 0b0100000 (0x20)
Radio Display LED PWM Control

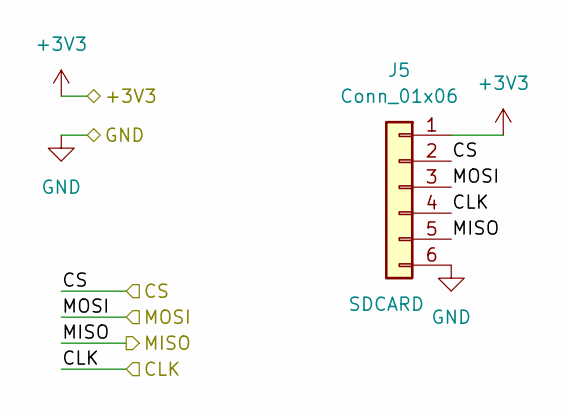
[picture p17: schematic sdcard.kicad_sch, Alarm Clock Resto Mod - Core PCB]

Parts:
J5: Conn_01x06; PinSocket_1x06_P2.54mm_Vertical

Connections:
+3V3: J5.1; also elsewhere on the board
/processor/SDCARD_CS: J5.2; also elsewhere on the board
/processor/SDCARD_MISO: J5.5; also elsewhere on the board
/processor/SDCARD_MOSI: J5.3; also elsewhere on the board
/processor/SDCARD_SCK: J5.4; also elsewhere on the board
GND: J5.6; also elsewhere on the board

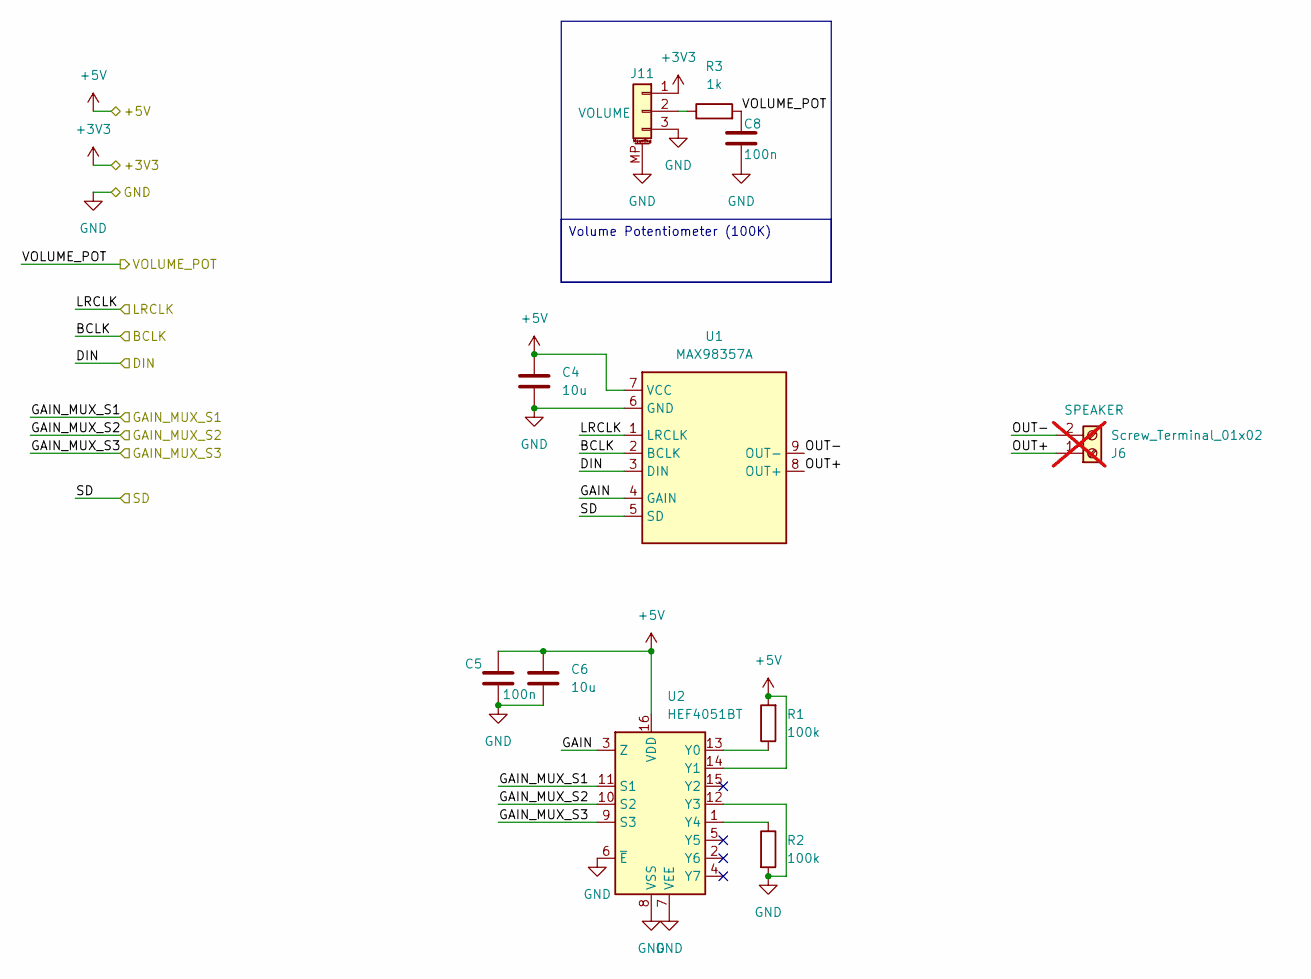
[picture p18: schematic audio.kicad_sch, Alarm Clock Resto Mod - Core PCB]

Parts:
C4, C6: 10u; C_0805_2012Metric_Pad1.18x1.45mm_HandSolder
C5, C8: 100n; C_0603_1608Metric_Pad1.08x0.95mm_HandSolder
J6: Screw_Terminal_01x02; TerminalBlock_Phoenix_PT-1,5-2-3.5-H_1x02_P3.50mm_Horizontal; not fitted
J11: Conn_01x03_MountingPin; Molex_PicoBlade_53261-0371_1x03-1MP_P1.25mm_Horizontal
R1, R2: 100k; R_0603_1608Metric_Pad0.98x0.95mm_HandSolder
R3: 1k; R_0603_1608Metric_Pad0.98x0.95mm_HandSolder
U1: MAX98357A; MAX98357A_Adafruit
U2: HEF4051BT; SOIC-16_3.9x9.9mm_P1.27mm

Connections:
+3V3: J11.1; also elsewhere on the board
+5V: C4.1, C5.1, C6.1, R1.2, U1.7 (VCC), U2.14 (Y1), U2.16 (VDD); also elsewhere on the board
/audio/BCLK: U1.2 (BCLK); also elsewhere on the board
/audio/DIN: U1.3 (DIN); also elsewhere on the board
/audio/GAIN: U1.4 (GAIN), U2.3 (Z)
/audio/GAIN_MUX_S1: U2.11 (S1); also elsewhere on the board
/audio/GAIN_MUX_S2: U2.10 (S2); also elsewhere on the board
/audio/GAIN_MUX_S3: U2.9 (S3); also elsewhere on the board
/audio/LRCLK: U1.1 (LRCLK); also elsewhere on the board
/audio/OUT+: J6.1, U1.8 (OUT+)
/audio/OUT-: J6.2, U1.9 (OUT-)
/audio/SD: U1.5 (SD); also elsewhere on the board
/audio/VOLUME_POT: C8.1, R3.2; also elsewhere on the board
GND: C4.2, C5.2, C6.2, C8.2, J11.3, J11.MP (MountPin), R2.2, U1.6 (GND), U2.6 (~E), U2.7 (VEE), U2.8 (VSS), U2.12 (Y3); also elsewhere on the board
unnamed: J11.2, R3.1
unnamed: R1.1, U2.13 (Y0)
unnamed: R2.1, U2.1 (Y4)

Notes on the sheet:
Volume Potentiometer (100K)

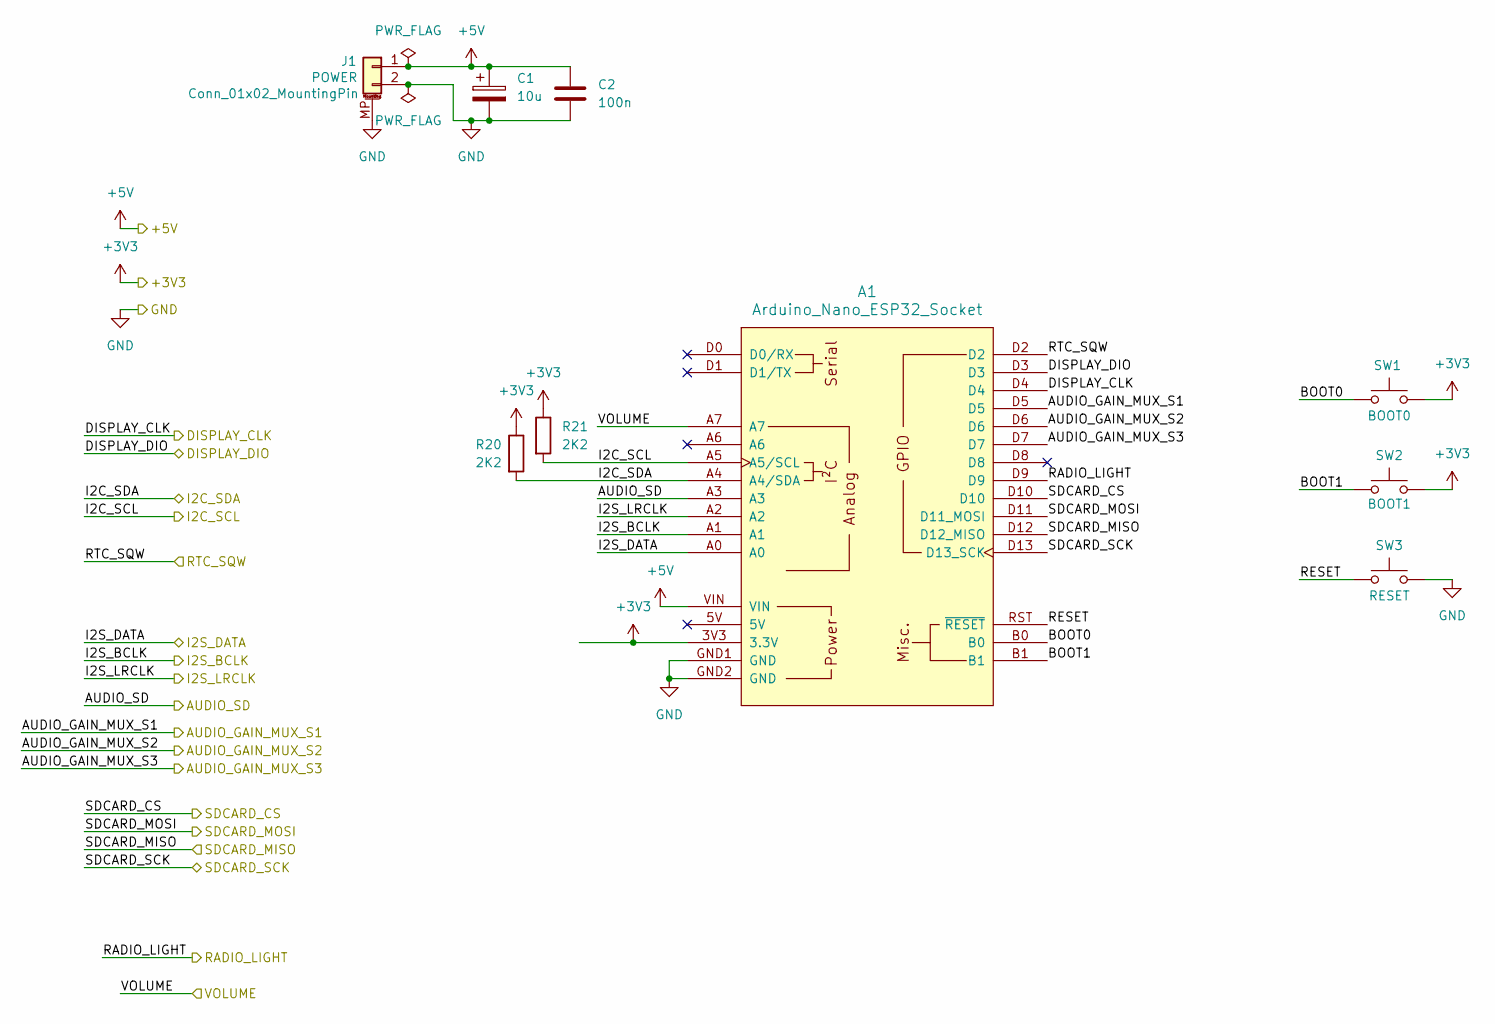
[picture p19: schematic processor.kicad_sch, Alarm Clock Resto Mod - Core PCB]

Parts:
A1: Arduino_Nano_ESP32_Socket
C1: 10u; CP_Radial_D4.0mm_P2.00mm
C2: 100n; C_0603_1608Metric_Pad1.08x0.95mm_HandSolder
J1: Conn_01x02_MountingPin; JST_S2B-XH-SM4-TB
R20, R21: 2K2; R_0603_1608Metric_Pad0.98x0.95mm_HandSolder
SW1, SW2, SW3: SW_Push; SW_PUSH_6mm

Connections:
+3V3: A1.3V3 (3.3V), R20.1, R21.1, SW1.2, SW2.2; also elsewhere on the board
+5V: A1.VIN, C1.1, C2.1, J1.1; also elsewhere on the board
/audio/BCLK: A1.A1; also elsewhere on the board
/audio/DIN: A1.A0; also elsewhere on the board
/audio/GAIN_MUX_S1: A1.D5; also elsewhere on the board
/audio/GAIN_MUX_S2: A1.D6; also elsewhere on the board
/audio/GAIN_MUX_S3: A1.D7; also elsewhere on the board
/audio/LRCLK: A1.A2; also elsewhere on the board
/audio/SD: A1.A3; also elsewhere on the board
/audio/VOLUME_POT: A1.A7; also elsewhere on the board
/buttons/DISPLAY_LED: A1.D9; also elsewhere on the board
/buttons/SCL: A1.A5 (A5/SCL), R21.2; also elsewhere on the board
/buttons/SDA: A1.A4 (A4/SDA), R20.2; also elsewhere on the board
/display/DISPLAY_CLK: A1.D4; also elsewhere on the board
/display/DISPLAY_DIO: A1.D3; also elsewhere on the board
/display/RTC_SQW: A1.D2; also elsewhere on the board
/processor/BOOT0: A1.B0, SW1.1
/processor/BOOT1: A1.B1, SW2.1
/processor/RESET: A1.RST (~RESET), SW3.1
/processor/SDCARD_CS: A1.D10; also elsewhere on the board
/processor/SDCARD_MISO: A1.D12 (D12_MISO); also elsewhere on the board
/processor/SDCARD_MOSI: A1.D11 (D11_MOSI); also elsewhere on the board
/processor/SDCARD_SCK: A1.D13 (D13_SCK); also elsewhere on the board
GND: A1.GND1 (GND), A1.GND2 (GND), C1.2, C2.2, J1.2, J1.MP (MountPin), SW3.2; also elsewhere on the board

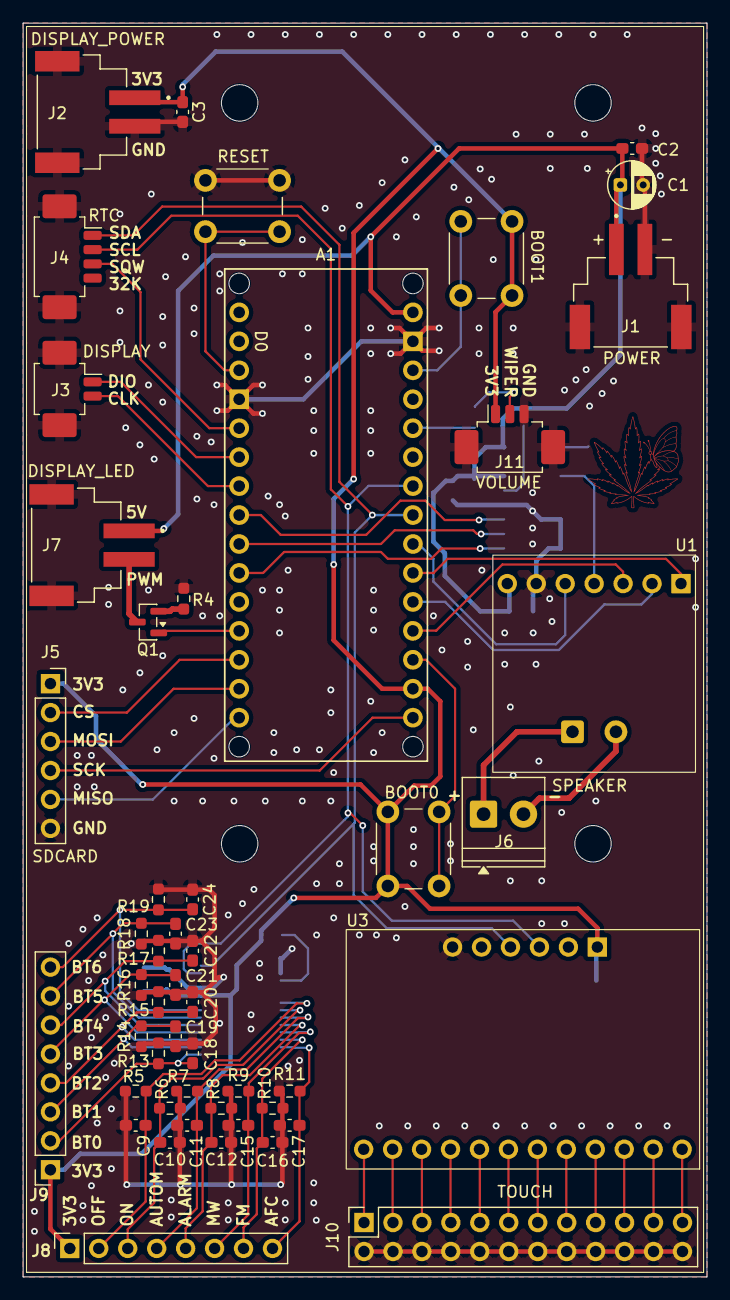
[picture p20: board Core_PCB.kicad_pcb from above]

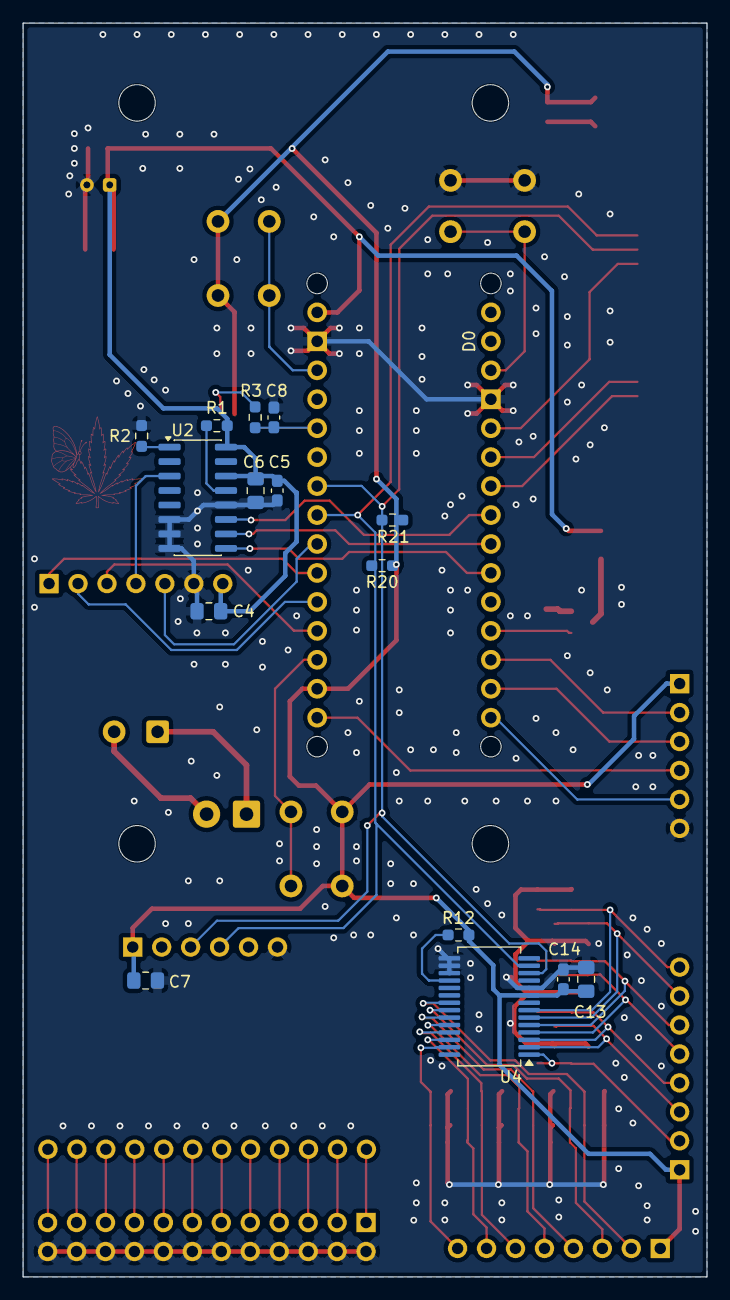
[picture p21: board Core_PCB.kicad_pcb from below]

Board: 2 copper layers, 60.0 x 110.0 mm, 70 parts (15 on the bottom side), 59 nets.

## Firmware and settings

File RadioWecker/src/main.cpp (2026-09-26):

#include <Arduino.h>

#include <HardwareConfig.h>
#include <SoftwareConfig.h>

#include <AlarmController.h>
#include <ButtonReader.h>
#include <ClockController.h>
#include <DisplayManager.h>
#include <GeneralConfigController.h>
#include <OnboardLedController.h>
#include <CLIController.h>
#include <SdController.h>
#include <SoundController.h>
#include <WiFiController.h>
#include <WebServerController.h>

//#define ONBOARDLED_OFF
//#define DISPLAY_OFF
//#define SDCARD_OFF
//#define SOUND_OFF
//#define WIRELESS_OFF
//#define WEBSERVER_OFF
//#define BUTTONS_OFF
//#define ALARMS_OFF
//#define CLOCK_OFF
//#define GENERALCONFIG_OFF
//#define CLI_OFF

typedef struct modules_ {
  OnboardLedController *led;
  DisplayManager *display;
  SdController *sd_card;
  SoundController *sound;
  WiFiController *wifi;
  WebServerController *webserver;
  ButtonReader *buttons;
  AlarmController *alarm;
  ClockController *clock;
  GeneralConfigController *config;
  CLIController *cli;
} Modules;

Modules modules;

void create_modules() {
  memset(&modules, 0, sizeof(Modules));

#ifndef ONBOARDLED_OFF
  modules.led = new OnboardLedController(ONBOARD_LED_PIN, 500);
#endif

#ifndef SDCARD_OFF
  modules.sd_card = new SdController( SD_SPI_CS_PIN,
                                      SD_SPI_SCK_PIN,
                                      SD_SPI_MISO_PIN,
                                      SD_SPI_MOSI_PIN,
                                      SD_SPI_FREQUENCY_HZ);
#endif

#ifndef DISPLAY_OFF
  modules.display = new DisplayManager( DISPLAY_CLK_PIN,
                                        DISPLAY_DIO_PIN,
                                        DISPLAY_SEPARATOR_MODE_DEFAULT);
#endif

#ifndef CLOCK_OFF
  modules.clock = new ClockController(RTC_SQW_PIN,
                                      RTC_I2C_SDA_PIN,
                                      RTC_I2C_SCL_PIN,
                                      RTC_I2C_FREQUENCY_HZ);
#endif

#ifndef ALARMS_OFF
  modules.alarm = new AlarmController(modules.sd_card);
#endif

#ifndef SOUND_OFF
  SoundController::HardwareConfig hwConfig = {
    .i2sBclkPin = I2S_BCLK_PIN,
    .i2sLrclkPin = I2S_LRCLK_PIN,
    .i2sDataPin = I2S_DATA_PIN,
    .SDPin = AUDIO_SD,
    .GAINMuxS1Pin = AUDIO_GAIN_MUX_S1,
    .GAINMuxS2Pin = AUDIO_GAIN_MUX_S2,
    .GAINMuxS3Pin = AUDIO_GAIN_MUX_S3,
    .volumePotentiometerPin = AUDIO_VOLUME_POT
  };
  modules.sound = new SoundController(modules.sd_card,
                                      &hwConfig);
#endif

#ifndef GENERALCONFIG_OFF
  modules.config = new GeneralConfigController(modules.sd_card);
#endif

#ifndef WEBSERVER_OFF
  modules.webserver = new WebServerController(modules.alarm,
                                              modules.clock,
                                              modules.sd_card,
                                              modules.sound,
                                              modules.display,
                                              modules.config);
#endif

#ifndef WIRELESS_OFF
  modules.wifi = new WiFiController();
#endif

#ifndef BUTTONS_OFF
  ButtonReader::HardwareConfig ButtonsHWConfig = {
    .i2cSdaPin = RADIO_BUTTONS_I2C_SDA_PIN,
    .i2cSclPin = RADIO_BUTTONS_I2C_SCL_PIN,
    .i2cFrequencyHz = RADIO_BUTTONS_I2C_FREQUENCY_HZ,
    .i2cAddress = RADIO_BUTTONS_I2C_ADDRESS
  };
  ButtonReader::ButtonsChannels buttonsChannels = {
    .RADIO_OFF = RADIO_BUTTON_OFF_CHANNEL,
    .RADIO_ON = RADIO_BUTTON_ON_CHANNEL,
    .RADIO_AUTOM = RADIO_BUTTON_AUTOM_CHANNEL,
    .RADIO_ALARM = RADIO_BUTTON_ALARM_CHANNEL,
    .RADIO_MW = RADIO_BUTTON_MW_CHANNEL,
    .RADIO_FM = RADIO_BUTTON_FM_CHANNEL,
    .RADIO_AFC = RADIO_BUTTON_AFC_CHANNEL,
    .DISPLAY_SLOW = DISPLAY_BUTTON_SLOW_CHANNEL,
    .DISPLAY_FAST = DISPLAY_BUTTON_FAST_CHANNEL,
    .DISPLAY_SLEEP_TOP = DISPLAY_BUTTON_SLEEP_TOP_CHANNEL,
    .DISPLAY_SIGNAL = DISPLAY_BUTTON_SIGNAL_CHANNEL,
    .DISPLAY_TIME = DISPLAY_BUTTON_TIME_CHANNEL,
    .DISPLAY_SLEEP_FRONT = DISPLAY_BUTTON_SLEEP_FRONT_CHANNEL,
    .DISPLAY_ILLUM = DISPLAY_BUTTON_ILLUM_CHANNEL
  };
  modules.buttons = new ButtonReader(&ButtonsHWConfig,
                                     &buttonsChannels);
#endif

#ifndef CLI_OFF
  modules.cli = new CLIController(modules.clock,
                                  modules.sd_card,
                                  modules.alarm,
                                  modules.webserver,
                                  modules.buttons);
#endif
}


void initialize_modules() {
  if (modules.led) if (!modules.led->initialize()) {
    Serial.println("main: onboard LED initialization failed");
  }

  if (modules.sd_card) if (!modules.sd_card->initialize()) {
    Serial.println("main: SD Card initialization failed");
  }

  GeneralConfigController::ConfigData configData = {
    .hostname = WIFI_DEFAULT_HOSTNAME,
    .timezonePosix = RTC_TIMEZONE_POSIX_DEFAULT,
    .timeOffsetMinutes = RTC_TIME_OFFSET_MINUTES_DEFAULT,
    .brightness = DISPLAY_BRIGHTNESS_DEFAULT,
    .ftpUsername = DEFAULT_FTP_USERNAME,
    .ftpPassword = DEFAULT_FTP_PASSWORD
  };
  if (modules.config) if (!modules.config->initialize(&configData)) {
    Serial.println("main: general configuration initialization failed");
  }

  if (modules.display) if (!modules.display->initialize(modules.config ? modules.config->brightness() : DISPLAY_BRIGHTNESS_DEFAULT)) {
    Serial.println("main: display initialization failed");
  }

  WiFiController::WifiConfig wifiConfig = {
    .hostname = modules.config ? modules.config->hostname() : WIFI_DEFAULT_HOSTNAME,
    .config_portal_timeout_sec = WIFI_CONFIG_PORTAL_TIMEOUT_S
  };
  if (modules.wifi) { 
    if (!modules.wifi->initialize(&wifiConfig)) {
      Serial.println("main: WiFi initialization failed");
    }
  } else {
    WiFi.mode(WIFI_OFF);
  }

  if (modules.buttons) if (!modules.buttons->initialize(modules.display ? modules.display->display() : nullptr)) {
    Serial.println("main: button reader initialization failed");
  }

  ClockController::TimeConfig clockConfig = {
    .ntpServer = RTC_NTP_SERVER,
    .timezonePosix = modules.config ? modules.config->timezonePosix() : RTC_TIMEZONE_POSIX_DEFAULT,
    .timeOffsetMinutes = modules.config ? modules.config->timeOffsetMinutes() : RTC_TIME_OFFSET_MINUTES_DEFAULT,
    .daylightOffsetSeconds = RTC_NTP_DAYLIGHT_OFFSET_SECONDS,
    .ntpSyncIntervalMs = RTC_NTP_SYNC_INTERVAL_MS,
    .ntpRetryIntervalMs = RTC_NTP_RETRY_INTERVAL_MS
  };
  if (modules.clock) if (!modules.clock->initialize(&clockConfig)) {
    Serial.println("main: clock initialization failed");
  }

  if (modules.alarm) if (!modules.alarm->initialize()) {
    Serial.println("main: alarm initialization failed");
  }

  if (modules.sound) if (!modules.sound->initialize()) {
    Serial.println("main: sound initialization failed");
  }

  if (modules.webserver) if (!modules.webserver->initialize()) {
    Serial.println("main: web server initialization failed");
  }

  if (modules.cli) if (!modules.cli->initialize()) {
    Serial.println("main: CLI initialization failed");
  }
}


void setup() {
  Serial.begin(115200);

  create_modules();

  initialize_modules();

  delay(800);
}


void loop() {
  if (modules.display) modules.display->showTimeHHMM(modules.clock ? modules.clock->displayValueHHMM() : 8888);
}

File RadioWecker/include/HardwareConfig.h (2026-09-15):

#pragma once

#include <Arduino.h>

/* Arduino Nano S3
                 ___
D13 - GPIO48 ---|   |--- D12 - GPIO47
3V3          ---|   |--- D11 - GPIO38
B0 - GPIO46  ---|   |--- D10 - GPIO21
A0 - GPIO1   ---|   |--- D9 - GPIO18
A1 - GPIO2   ---|   |--- D8 - GPIO17
A2 - GPIO3   ---|   |--- D7 - GPIO10
A3 - GPIO4   ---|   |--- D6 - GPIO9
A4 - GPIO11  ---|   |--- D5 - GPIO8
A5 - GPIO12  ---|   |--- D4 - GPIO7
A6 - GPIO13  ---|   |--- D3 - GPIO6
A7 - GPIO14  ---|   |--- D2 - GPIO5
VBUS         ---|   |--- GND
B1 - GPIO0   ---|   |--- RST
GND          ---|   |--- D0 - GPIO44
VIN          ---|___|--- D1 - GPIO43

*/

// on board LED
static constexpr uint8_t ONBOARD_LED_PIN = LED_RED;//46;

// shared I2C
static constexpr uint8_t I2C_SDA_PIN = A4;
static constexpr uint8_t I2C_SCL_PIN = A5;
static constexpr uint32_t I2C_FREQ_HZ = 100000;

// Display - TM1637
static constexpr uint8_t DISPLAY_CLK_PIN = D4;
static constexpr uint8_t DISPLAY_DIO_PIN = D3;

// todo: the TM1637 can only read one button at a time - move them to the MCP
static constexpr uint8_t DISPLAY_BUTTON_SLOW_GRID = 1;
static constexpr uint8_t DISPLAY_BUTTON_SLOW_KEY = 1;
static constexpr uint8_t DISPLAY_BUTTON_FAST_GRID = 1;
static constexpr uint8_t DISPLAY_BUTTON_FAST_KEY = 2;
static constexpr uint8_t DISPLAY_BUTTON_SLEEP_TOP_GRID = 2;
static constexpr uint8_t DISPLAY_BUTTON_SLEEP_TOP_KEY = 2;
static constexpr uint8_t DISPLAY_BUTTON_SIGNAL_GRID = 3;
static constexpr uint8_t DISPLAY_BUTTON_SIGNAL_KEY = 1;
static constexpr uint8_t DISPLAY_BUTTON_TIME_GRID = 3;
static constexpr uint8_t DISPLAY_BUTTON_TIME_KEY = 2;
static constexpr uint8_t DISPLAY_BUTTON_SLEEP_FRONT_GRID = 4;
static constexpr uint8_t DISPLAY_BUTTON_SLEEP_FRONT_KEY = 1;
static constexpr uint8_t DISPLAY_BUTTON_ILLUM_GRID = 4;
static constexpr uint8_t DISPLAY_BUTTON_ILLUM_KEY = 2;

static constexpr uint8_t DISPLAY_BUTTON_SLOW_CHANNEL = 99; //last one to check
static constexpr uint8_t DISPLAY_BUTTON_FAST_CHANNEL = 0;
static constexpr uint8_t DISPLAY_BUTTON_SLEEP_TOP_CHANNEL = 1;
static constexpr uint8_t DISPLAY_BUTTON_SIGNAL_CHANNEL = 10;
static constexpr uint8_t DISPLAY_BUTTON_TIME_CHANNEL = 2;
static constexpr uint8_t DISPLAY_BUTTON_SLEEP_FRONT_CHANNEL = 13;
static constexpr uint8_t DISPLAY_BUTTON_ILLUM_CHANNEL = 5;

// SD Card
static constexpr uint8_t SD_SPI_CS_PIN = D10;
static constexpr uint8_t SD_SPI_SCK_PIN = D13;
static constexpr uint8_t SD_SPI_MISO_PIN = D12;
static constexpr uint8_t SD_SPI_MOSI_PIN = D11;
static constexpr uint32_t SD_SPI_FREQUENCY_HZ = 10000000;

// RTC
static constexpr uint8_t RTC_I2C_SDA_PIN = I2C_SDA_PIN;
static constexpr uint8_t RTC_I2C_SCL_PIN = I2C_SCL_PIN;
static constexpr uint32_t RTC_I2C_FREQUENCY_HZ = I2C_FREQ_HZ;
static constexpr uint8_t RTC_SQW_PIN = D2;

// Audio - I2S - MAX9357A
static constexpr uint8_t I2S_LRCLK_PIN = 3; //A2;
static constexpr uint8_t I2S_BCLK_PIN = 2; //A1;
static constexpr uint8_t I2S_DATA_PIN = 1; //A0;
static constexpr uint8_t AUDIO_SD = A3;
static constexpr uint8_t AUDIO_GAIN_MUX_S1 = D5; // gain is controlled by HEF4051BT
static constexpr uint8_t AUDIO_GAIN_MUX_S2 = D6;
static constexpr uint8_t AUDIO_GAIN_MUX_S3 = D7;
static constexpr uint8_t AUDIO_VOLUME_POT = A7; // volume potentiometer is 100k
// Audio control
#define AUDIO_SHUTDOWN_MODE_OFF()  do { pinMode(AUDIO_SD, OUTPUT); digitalWrite(AUDIO_SD, LOW); } while (0)
#define AUDIO_SHUTDOWN_MODE_ON()   pinMode(AUDIO_SD, OPEN_DRAIN)
static constexpr uint8_t AUDIO_GAIN_3DB = 0b000;
static constexpr uint8_t AUDIO_GAIN_6DB = 0b100;
static constexpr uint8_t AUDIO_GAIN_9DB = 0b010;
static constexpr uint8_t AUDIO_GAIN_12DB = 0b110;
static constexpr uint8_t AUDIO_GAIN_15DB = 0b001;

// Light
static constexpr uint8_t LIGHT_PWM_PIN = D9;
static constexpr uint16_t LIGHT_PWM_FREQUENCY = 10000; // Hz

// Radio Dial - MPR121
static constexpr uint8_t RADIO_DIAL_I2C_SDA_PIN = I2C_SDA_PIN;
static constexpr uint8_t RADIO_DIAL_I2C_SCL_PIN = I2C_SCL_PIN;
static constexpr uint32_t RADIO_DIAL_I2C_FREQUENCY_HZ = I2C_FREQ_HZ;

// Radio Buttons - MCP23017
static constexpr uint8_t RADIO_BUTTONS_I2C_SDA_PIN = I2C_SDA_PIN;
static constexpr uint8_t RADIO_BUTTONS_I2C_SCL_PIN = I2C_SCL_PIN;
static constexpr uint32_t RADIO_BUTTONS_I2C_FREQUENCY_HZ = I2C_FREQ_HZ;
static constexpr uint8_t RADIO_BUTTONS_I2C_ADDRESS = 0x20;

static constexpr uint8_t RADIO_BUTTON_OFF_CHANNEL = 0; //GPA0
static constexpr uint8_t RADIO_BUTTON_ON_CHANNEL = 1; //GPA1
static constexpr uint8_t RADIO_BUTTON_AUTOM_CHANNEL = 2; //GPA2
static constexpr uint8_t RADIO_BUTTON_ALARM_CHANNEL = 3; //GPA3
static constexpr uint8_t RADIO_BUTTON_MW_CHANNEL = 4; //GPA4
static constexpr uint8_t RADIO_BUTTON_FM_CHANNEL = 5; //GPA5
static constexpr uint8_t RADIO_BUTTON_AFC_CHANNEL = 6; //GPA6

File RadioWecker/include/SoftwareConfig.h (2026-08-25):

#pragma once
#include <Arduino.h>

#include <HardwareConfig.h>
#include <DisplayManager.h>

// Wifi
static constexpr uint16_t WIFI_CONFIG_PORTAL_TIMEOUT_S = 300;
static constexpr const char* WIFI_DEFAULT_HOSTNAME = "RadioWecker";
static constexpr const char* DEFAULT_FTP_USERNAME = "radiowecker";
static constexpr const char* DEFAULT_FTP_PASSWORD = "radiowecker";

// Display - TM1637
static constexpr uint8_t DISPLAY_BRIGHTNESS_DEFAULT = 1;
static constexpr DisplayManager::SeparatorMode DISPLAY_SEPARATOR_MODE_DEFAULT = DisplayManager::SeparatorMode::Dots;

// RTC - DS3231
static constexpr const char* RTC_NTP_SERVER = "pool.ntp.org";
static constexpr long RTC_NTP_GMT_OFFSET_SECONDS = 0;
static constexpr int RTC_NTP_DAYLIGHT_OFFSET_SECONDS = 0;
static constexpr uint32_t RTC_NTP_SYNC_INTERVAL_MS = 6UL * 60UL * 60UL * 1000UL;
static constexpr uint32_t RTC_NTP_RETRY_INTERVAL_MS = 60UL * 1000UL;
static constexpr const char* RTC_TIMEZONE_POSIX_DEFAULT = "UTC0";
static constexpr int16_t RTC_TIME_OFFSET_MINUTES_DEFAULT = 0;

// Radio Dial - read via MPR121
static constexpr uint8_t RADIO_BUTTON_DIAL0_CHANNEL = 0; ///E0
static constexpr uint8_t RADIO_BUTTON_DIAL1_CHANNEL = 1; ///E1
static constexpr uint8_t RADIO_BUTTON_DIAL2_CHANNEL = 2; ///E2
static constexpr uint8_t RADIO_BUTTON_DIAL3_CHANNEL = 3; ///E3

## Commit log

2026-05-13 project setup with pioarduino, simple program to test tm1637 4 digit 7seg display, vibe coded on board led controller, base files for wokwi simulation
2026-05-13 added a rtc clock and microsd card to diagram, moved the display to software SPI, vibe coded a simple selftest for the sd card
2026-05-13 added a driver for the RTC, removed the counter, show colon if time is shown
2026-05-13 added the square wave pin from the rtc, so we dont have to use the i2c all the time
2026-05-21 added explicit hardware config to the sd card spi and rtc i2c
2026-05-21 onboard led is shared with SCK pin, so moved it to the RGB led
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2026-06-03 better sound player page, better controls, removed the radio (will add to its own page), more complete track list explorer
2026-06-17 initial schematics. still missing interfaces connections
    [Telefunken_Digitale_Electronic_101.kicad_pcb, Telefunken_Digitale_Electronic_101.kicad_sch, buttons.kicad_sch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]
2026-06-17 SCH - buttons: added footprints, name is under Name instead of Reference and Reference follows normal "J?"
    [buttons.kicad_sch]
2026-06-17 SCH - display: name under Name
    [display.kicad_sch]
2026-06-17 SCH - rtc: adjusted footprints and direction of 32K label
    [rtc.kicad_sch]
2026-06-17 SCH - interface: added connectors (JST connectors) and labels
    [interface.kicad_sch]
2026-06-17 SCH - top level: connected everything
    [Telefunken_Digitale_Electronic_101.kicad_sch]
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2026-06-18 SCH - buttons: added footprints to switches (will probably change, need a lower profile)
    [buttons.kicad_sch]
2026-06-18 SCH - interface: name under Name and reference follows J?
    [interface.kicad_sch]
2026-06-18 PCB: positioning of critical parts and board shape according to original. initial positioning of all components
    [Telefunken_Digitale_Electronic_101.kicad_pcb]
2026-06-18 PCB: initial layout idea
    [Telefunken_Digitale_Electronic_101.kicad_pcb, interface.kicad_sch]
2026-06-18 SCH - buttons, display and interface: TM1637 can read the buttons (saves many resistors, caps and connectors)
    [buttons.kicad_sch, display.kicad_sch, interface.kicad_sch]
2026-06-18 SCH - top level: reflect new button reading strategy
    [Telefunken_Digitale_Electronic_101.kicad_sch]
2026-06-18 PCB: updated with new button reading strategy (still missing VCC and GND routing)
    [Telefunken_Digitale_Electronic_101.kicad_pcb]
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2026-06-19 SCH - buttons: added a table with which button is connected to where on the TM1637
    [buttons.kicad_sch]
2026-06-19 PCB: refined layout, added GND planes, connected VCC
    [Telefunken_Digitale_Electronic_101.kicad_pcb]
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2026-06-19 SCH and PCB: added the Mounting Pads (a few chosen ones)
    [Telefunken_Digitale_Electronic_101.kicad_pcb, Telefunken_Digitale_Electronic_101.kicad_sch, interface.kicad_sch]
2026-06-19 SCH - interface: replaced symbols from connectors with mounting pads to contain the mounting pads (and connected them to GND)
    [Telefunken_Digitale_Electronic_101.kicad_pcb, interface.kicad_sch]
2026-06-19 SCH and PCB: reannotated everything
    [Telefunken_Digitale_Electronic_101.kicad_pcb, buttons.kicad_sch, display.kicad_sch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]
2026-06-30 adjusted connectors footprints, added footprint to input polarized capacitor, rtc and display polarized capacitors converted to non polarized
    [Telefunken_Digitale_Electronic_101.kicad_pcb, display.kicad_sch, interface.kicad_sch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]
2026-07-01 SCH and PCB - buttons: added proper switches that will be used
    [Telefunken_Digitale_Electronic_101.kicad_pcb, buttons.kicad_sch]
2026-07-06 SCH: initial schematics and lib components for the i2s audio driver and capacitance sensor
    [Core_PCB.kicad_pcb, Core_PCB.kicad_sch, audio.kicad_sch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]
2026-07-08 SCH: audio gain control via mux (HEF4051), buttons read via i2c io expander (MCP23017)
    [Core_PCB.kicad_sch, audio.kicad_sch, buttons.kicad_sch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]
2026-07-08 SCH: annotated sheets, reannotated all components
    [Core_PCB.kicad_sch, audio.kicad_sch, buttons.kicad_sch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]
2026-07-13 SCH: assigned footprints to what had missing, replaced some polarized caps with non polarized, added connector for capacitance sensor, ran electric test and fixed minor issues
    [Core_PCB.kicad_sch, audio.kicad_sch, buttons.kicad_sch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]
2026-07-13 fixed pin number for the output
2026-07-14 SCH - audio: screw terminal was facing the wrong direction; buttons: volume pot had wrong footprint, added +5V input; processor: use alternative arduino symbol and custom footprint (with 3d model), a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
    [Core_PCB.kicad_sch, audio.kicad_sch, buttons.kicad_sch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]
2026-07-14 PCB - initial PCB format and components placement
    [Core_PCB.kicad_pcb]
2026-07-14 PCB - initial layout
    [Core_PCB.kicad_pcb, audio.kicad_sch, processor.kicad_sch]
2026-07-24 use a potentiometer connector (picoblade) and moved it to the audio sch; touch interface (capacitance measureer) got a 2 row connector with GND on one line; added mounting screws and logo to the main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
    [Core_PCB.kicad_sch, audio.kicad_sch, buttons.kicad_sch]
2026-07-28 moved sch changes to PCB, screws placement is not definitive
    [Core_PCB.kicad_pcb]
2026-07-28 SCH: audio - forgot the +3V3 hierarchical label, renamed VCC to +5V, made screw terminal not populated (use the one on the i2s module) SCH general: bumped date
    [Core_PCB.kicad_sch, audio.kicad_sch, buttons.kicad_sch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]
2026-07-28 PCB: adjusted size and screws positions to correct values, new component positions, new layout and bumped the date
    [Core_PCB.kicad_pcb]
2026-07-30 TFK: sch - i2c resistors not populate, logo; pcb - spaced tracks, stitching vias, logo
    [Telefunken_Digitale_Electronic_101.kicad_pcb, interface.kicad_sch, rtc.kicad_sch]
2026-07-30 TFK: pcb - identification label consistent with core PCB
    [Telefunken_Digitale_Electronic_101.kicad_pcb]
2026-08-02 PCBs: updated logo; added I2C resistors to I2C (core pcb)
    [Core_PCB.kicad_pcb, Core_PCB.kicad_sch, Telefunken_Digitale_Electronic_101.kicad_pcb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]
2026-08-02 Release Version 1.0
    [Core_PCB.kicad_pcb]
2026-08-18 fixed BOM
    [Telefunken_Digitale_Electronic_101 - Version 1.0.csv, Telefunken_Digitale_Electronic_101 - Version 1.0.ods]
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2026-08-24 adjusted hw config according to PCBs v1.0, moved sw config to own file
2026-08-24 changed the display library for one that supports reading the buttons, adjusted on board led init function to follow other modules
2026-08-24 bugfix: wrong const sizes
    [HardwareConfig.h]
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2026-09-15 each module know when it's supposed to do something. removed the fail messages on the display (might implement it properly later)
    [main.cpp]
2026-09-15 found the correct channels for the display buttons
    [HardwareConfig.h]
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2026-09-16 clicontroller takes care of its own task, added a command to reboot the system
    [main.cpp]
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2026-10-11 clock: bugfixes RTC sync (use UTC) and first timer start (otherwise it waits for ntp sync to start)
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
